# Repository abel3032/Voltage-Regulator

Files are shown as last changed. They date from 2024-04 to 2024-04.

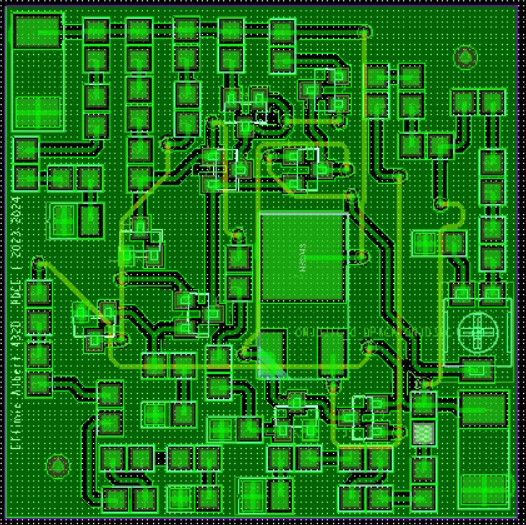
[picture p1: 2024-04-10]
Layout/layout.jpg

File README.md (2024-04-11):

Stabilizator de tensiune cu element de reglaj serie

Cu ajutorul programelor OrCAD, PSpice si PCBEditor am proiectat un stabilizator de tensiune cu element de reglaj serie respectand urmatoarele conditii:  
      -Tensiunea de la iesire reglabila in intervalul 6V - 12V   
      -Sarcina la iesire de 480 ohmi  
      -Deriva termica mai mica de 2mV/grad Celsius  
      -Protectia la suprasarcina prin limitarea temperaturii tranzistorului regulator serie la 120 grade Celsius si a curentului maxim la 0.5A  
      -Tensiunea de intrare in intervalul 21,6V - 24V  
      -Amplificarea in tensiune minima (in bucla deschisa) a amplificatorului de eroare minim 100    
      -Domeniul temperaturilor de functionare 0 - 60 grade Celsius    
      -Semnalizarea prezentei tensiunilor de intrare/iesire cu o dioda de tip LED

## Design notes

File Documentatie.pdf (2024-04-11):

# Universitatea “Politehnica” din Bucuresti

# FACULTATEA DE ELECTRONICA, TELECOMUNICATII SI TEHNOLOGIA INFORMATIEI

# STABILIZATOR DE TENSIUNE CU ERS

# Proiect 1

# Student: Eftimie Albert Gabriele

# Grupa: 432D

2023-2024

# 1. Date de proiectare

- N=12

# - Element de reglaj serie - Sarcina la iesire 480 ohmi - Deriva termica <2mV/grad Celsius

- Protecție la suprasarcină prin limitarea temperaturii tranzistorului regulator serie la 1200C, si a curentului maxim la 0,5A - Tensiunea de intrare in interval 21,6V-24V - Amplificarea în tensiune minimă (în buclă deschisă) a amplificatorului de eroare: minim 100 - Domeniul temperaturilor de funcționare: 0-60 Celsius (verificabil prin testare în temperatura) - Semnalizarea prezenței tensiunilor de intrare/ieșire cu diodă de tip LED

# 2. Schema bloc a circuitului

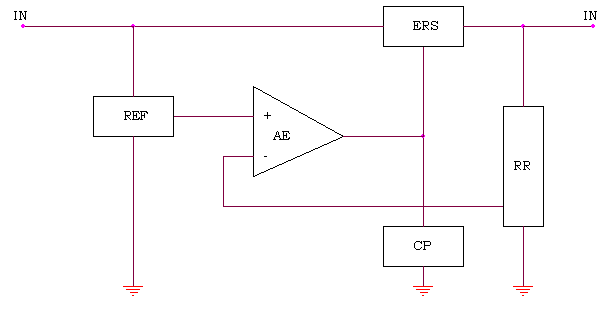
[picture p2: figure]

# 3. Schema electrica a circuitului

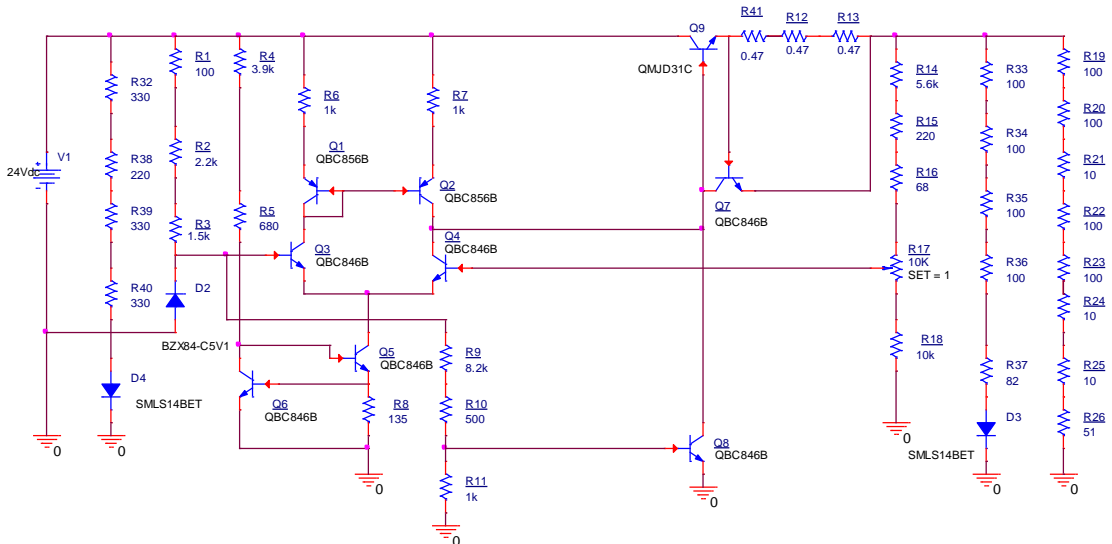
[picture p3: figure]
Q7 QBC846B; Q8 QBC846B; 24Vdc; SMLS14BET; R17 10K SET = 1; QMJD31C; BZX84-C5V1; Q1 QBC856B; Q2 QBC856B; Q3 QBC846B; Q4 QBC846B; Q5 QBC846B; Q6 QBC846B

# Blocurile componente ale stabilizatorului de tesniune sunt:

# -referinta de tensiune data de dioda Zener D2, polarizata de rezistoarele R1, R2 si R3; acestea s-au ales astfel incat prin dioda sa curga un curent de aprox 5 mA prin zener)

# -amplificatorul de eroare, alcatuit din Q3, Q4, amplificator alimentat la 2 surse de curent formate din R6, R7, Q1, Q2, respectiv R4, R5, R8, Q5, Q6; sursele de curent au fost dimensionate pentru a asigura prin ambele tranzistoare un curent aproximativ egal de 2.5mA

# -reteaua de reactie negativa formata din rezistoarele R14, R15, R16, R17, R18 (divizor de tensiune); Vout/Vin=10k/25.8k, unde Vout este tensiunea data de dioda Zener

# -circuitul de protectie la temperatura format din Q8, R9, R10 si R11; acesta a fost

dimensionat astfel pentru ca tensiunea baza-emitor a lui Q8 sa fie de 460-500mV,

# aceasta crescand odata cu cresterea temperaturii, la 120 grade celsius urmand sa se

0

# deschida tranzistorul. Tensiuneea Vbe este astfel setata cu ajutorul divizorului de

tesniune format din R9, R10 si R11.

# -circuitul de protectie la suprasarcina format din Q7, R12 si R13 a fost dimensionat astfel pentru a asigura o tensiune baza emitor de aprox 0.7V la un curent de 0.5A

# -elemntul de reglaj serie format din tranzistoarele Q9, s-a ales un tranzistor de putere in locul a ami multor tranzistori legati in paralel deoarece la capacitate maxima, asupra acestuia urma sa fie disipata o putere de peste 1.2W

# -cele 2 diode de semnalizare a tensiunii de la intrare si la iesire D2, D3 cu rezistoarele ce le polarizeaza R1, R2, R3 respectiv R33-R37

# 4. Simularile stabilizatorului

# -punctul static de functionare simulat(pentru potentiometrul setat pe 1 si tensiunea maxima de intrare)

# In figura de mai jos putem observa toti curentii din circuit

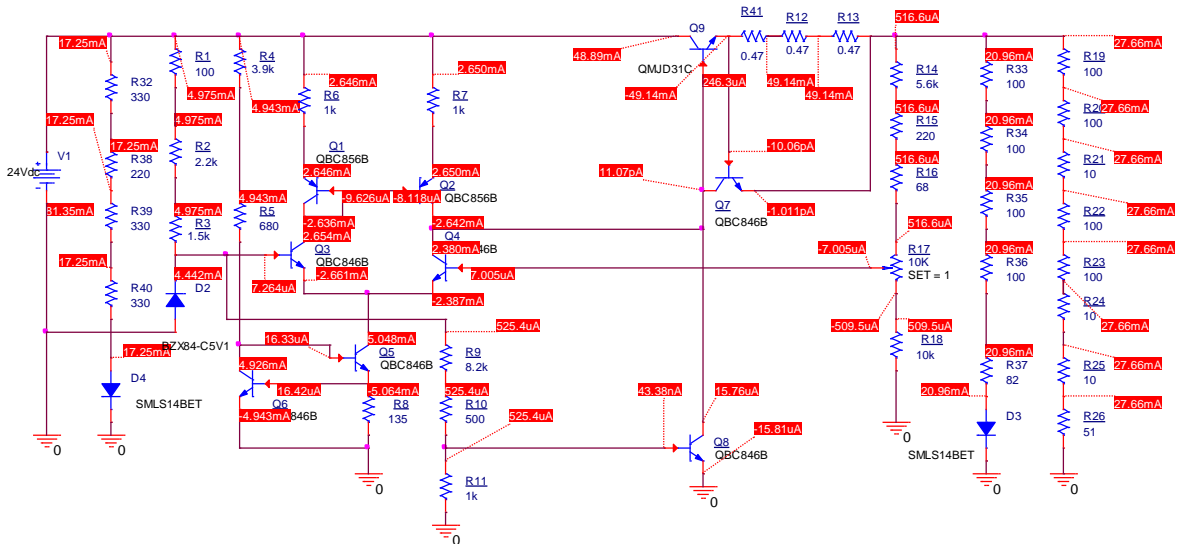
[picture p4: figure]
Q7 QBC846B; Q8 QBC846B; 24Vdc; SMLS14BET; R17 10K SET = 1; QMJD31C; BZX84-C5V1; Q1 QBC856B; Q2 -8.118uA QBC856B; Q3 QBC846B; QBC846B; Q5 QBC846B; Q6 QBC846B

0

# Se observa ca toate tranzistoarele bipolare sunt in regim activ de functionare(exceptie fac tranzistoarele din componenta circuitelor de protectie)

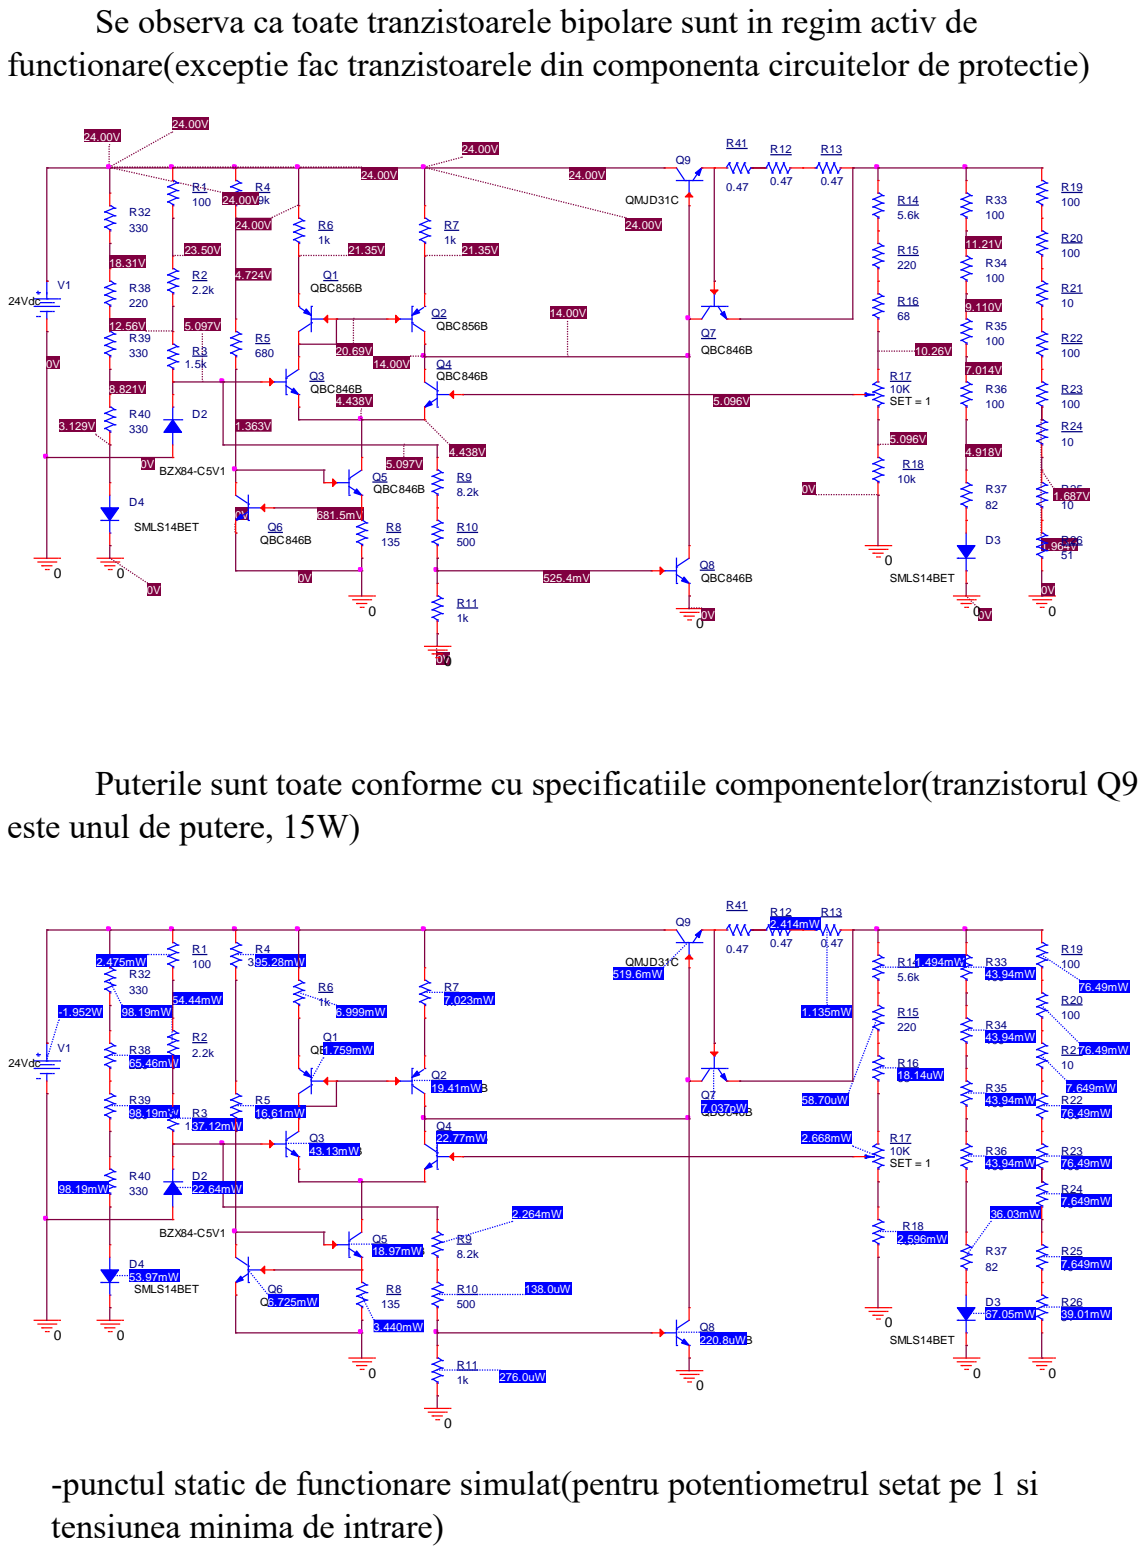
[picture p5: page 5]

Puterile sunt toate conforme cu specificatiile componentelor(tranzistorul Q9
este unul de putere, 15W)

-punctul static de functionare simulat(pentru potentiometrul setat pe 1 si
tensiunea minima de intrare)

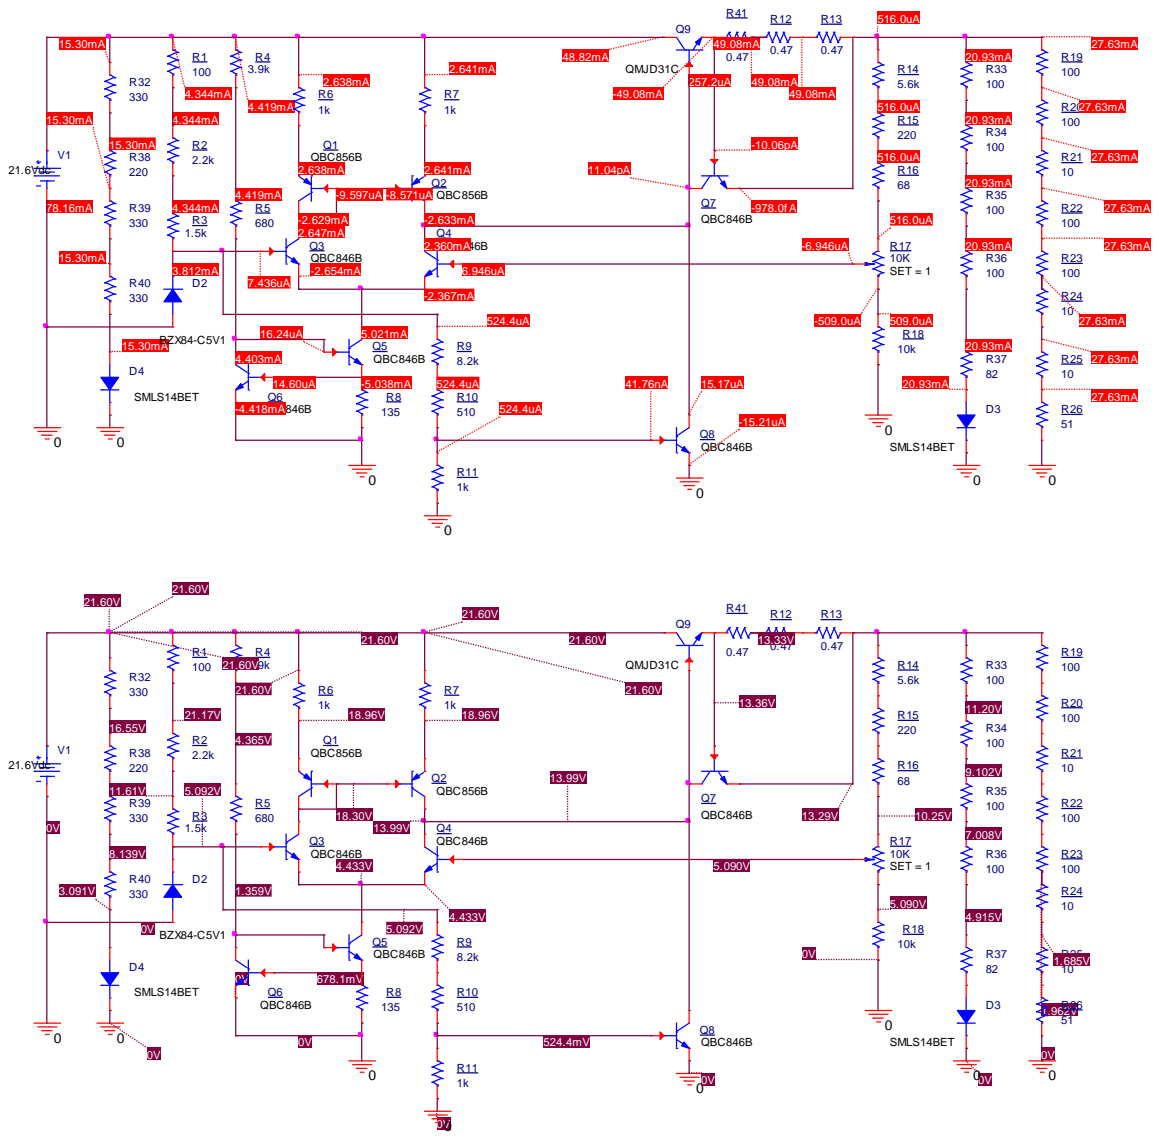
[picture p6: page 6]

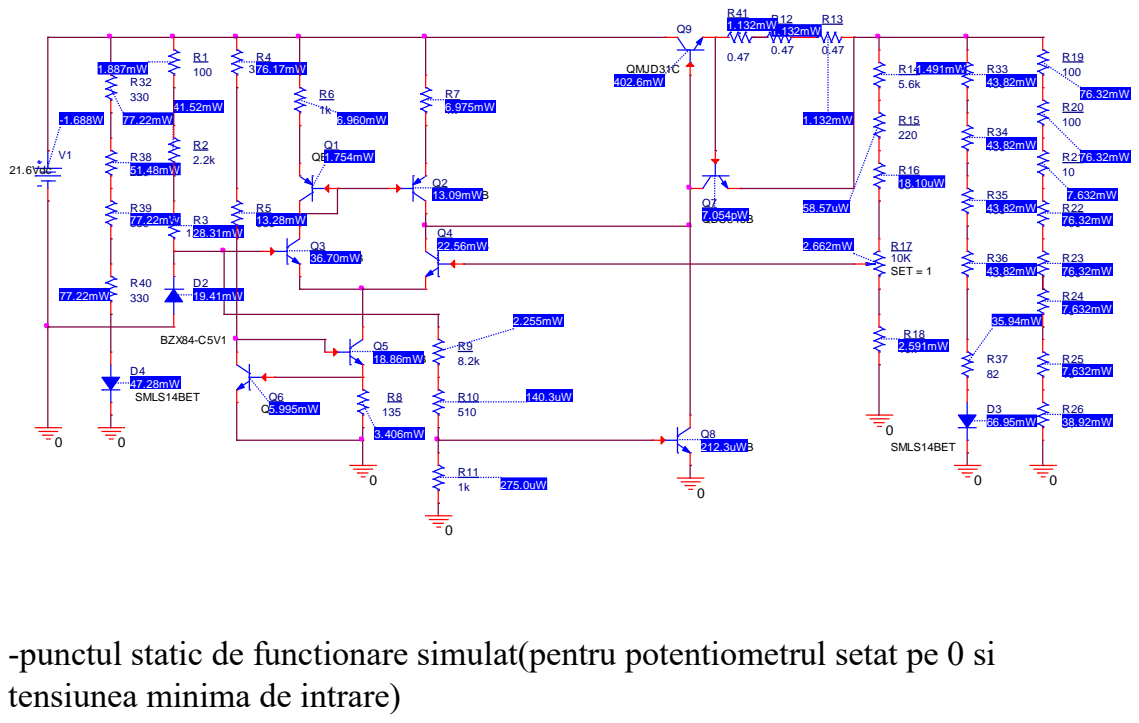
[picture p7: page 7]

-punctul static de functionare simulat(pentru potentiometrul setat pe 0 si
tensiunea minima de intrare)

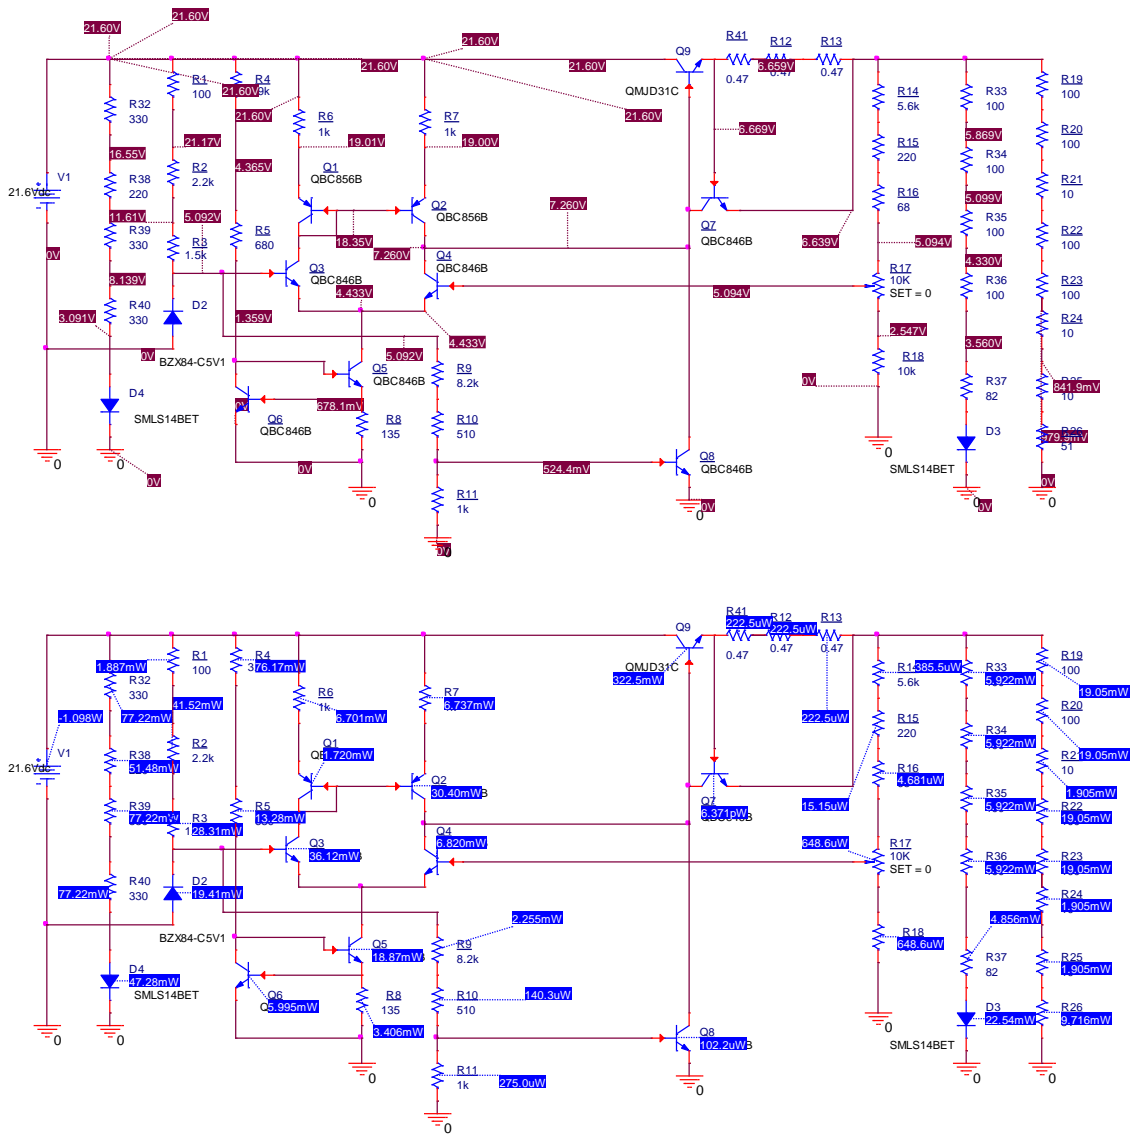
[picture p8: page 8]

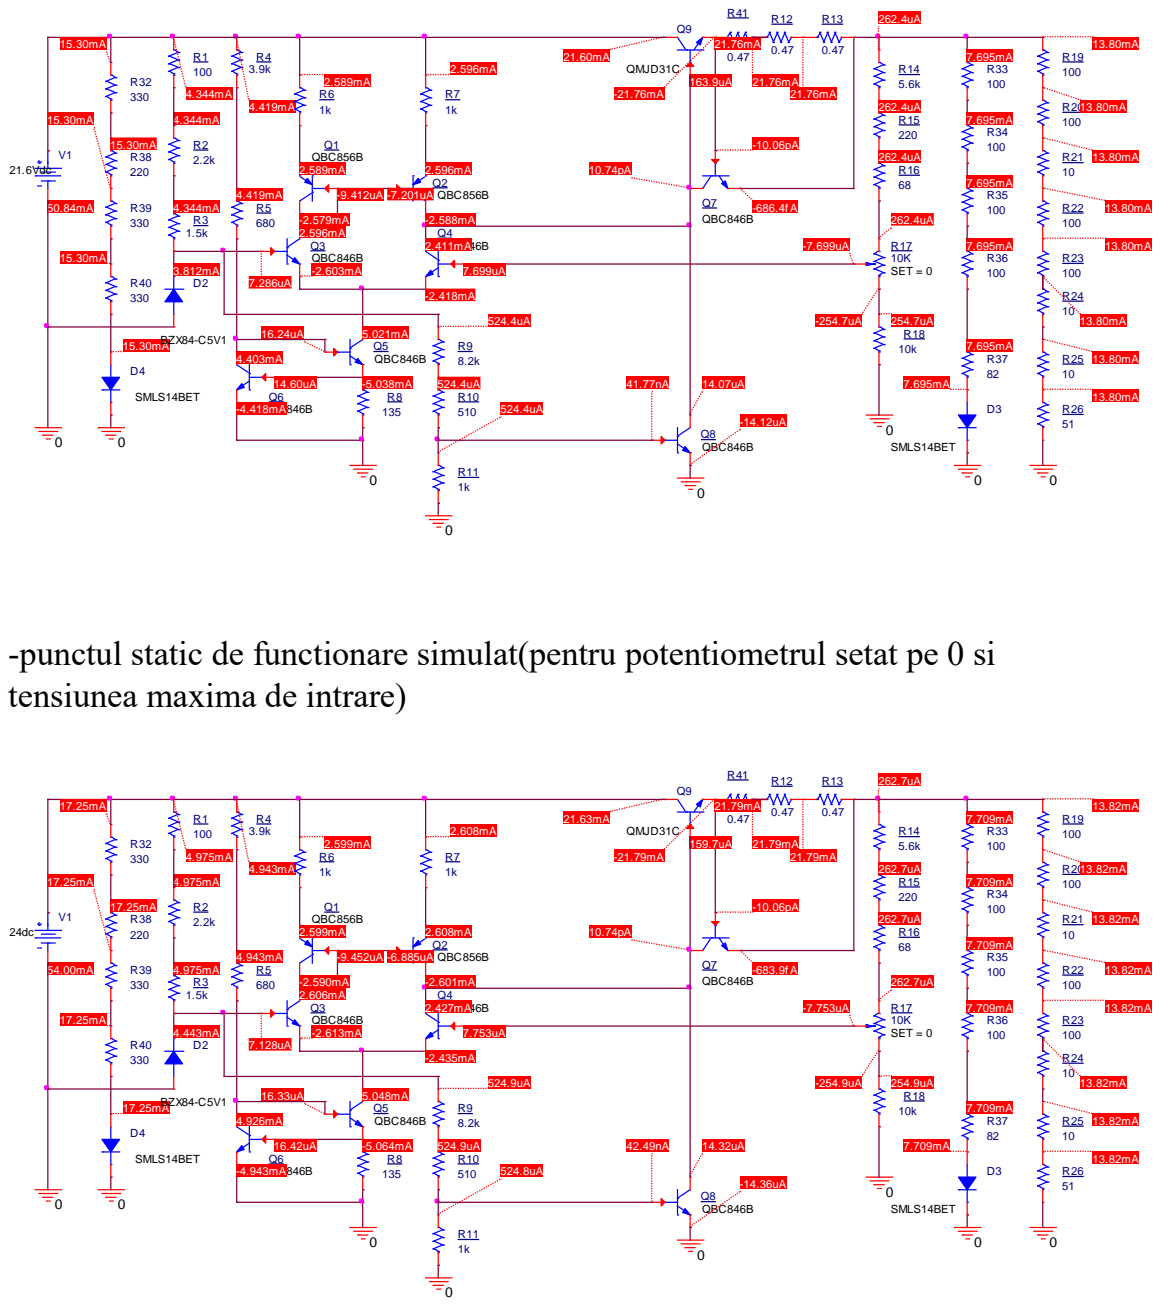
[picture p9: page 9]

-punctul static de functionare simulat(pentru potentiometrul setat pe 0 si
tensiunea maxima de intrare)

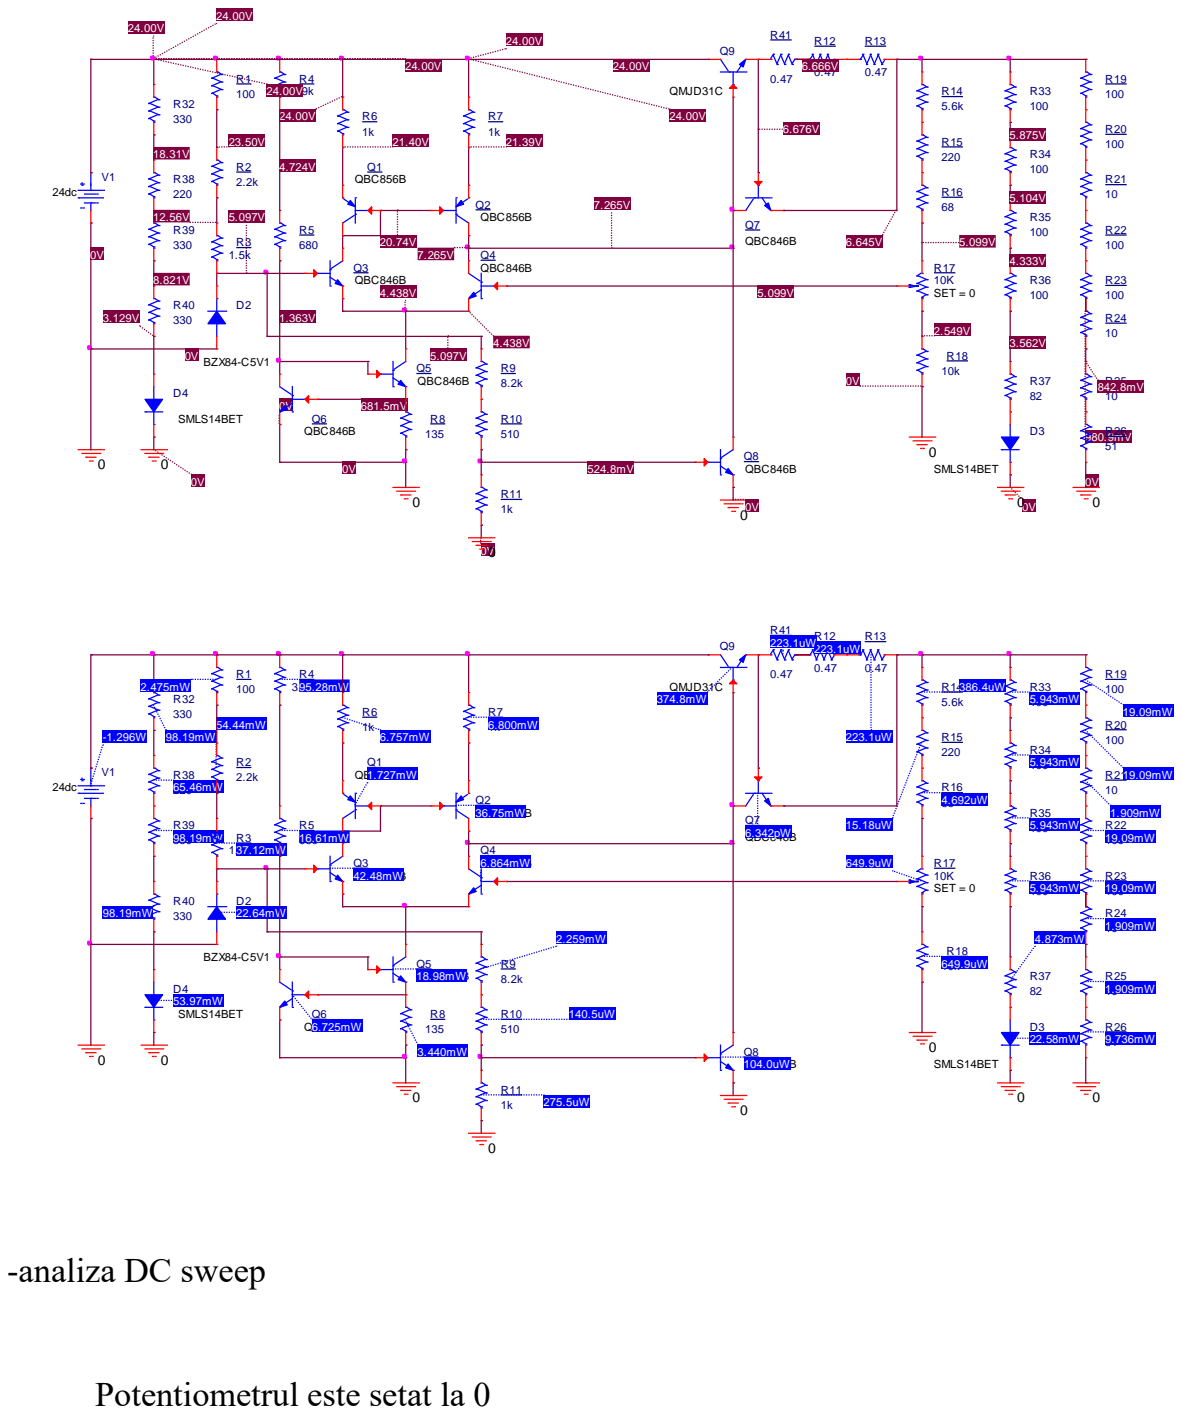
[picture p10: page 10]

Potentiometrul este setat la 0

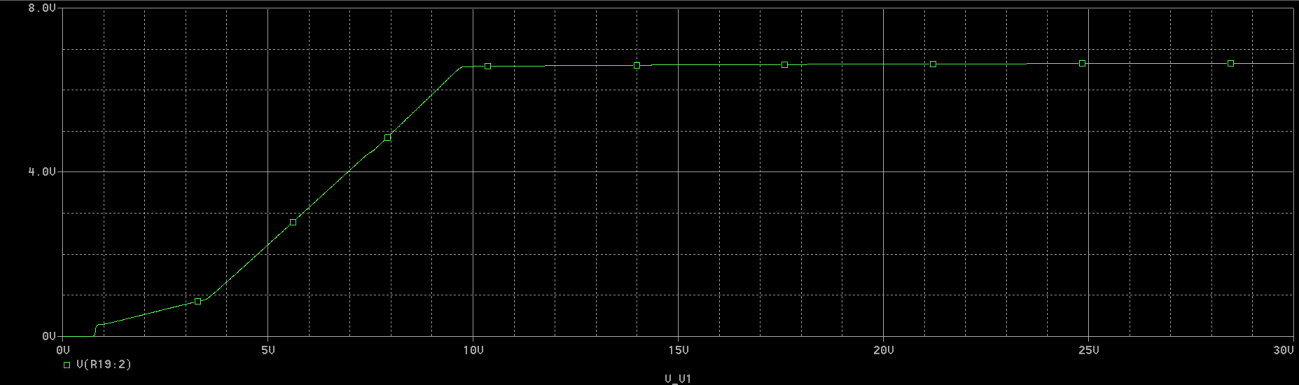
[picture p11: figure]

# Potentiometrul este setat la 1

# Am ales tensiuni de iesire cu 10% mai mari decat cele din cerinta din cauza

tolerantelor rezistoarelor.

Se observa ca intre tensiunile de intrare date in cerinta (21,6V – 24 V),

# tensiunile de iesire sunt constante in ambele cazuri, tensiunea de iesire avand o

variatie mai mica de 0.6mv/V .

# -domeniul temperaturilor de functionare

# -analiza s-a facut pentru temperaturile 0, 20, 40 respectiv 60 grade Celsius

# -pentru tensiunea minima la iesire

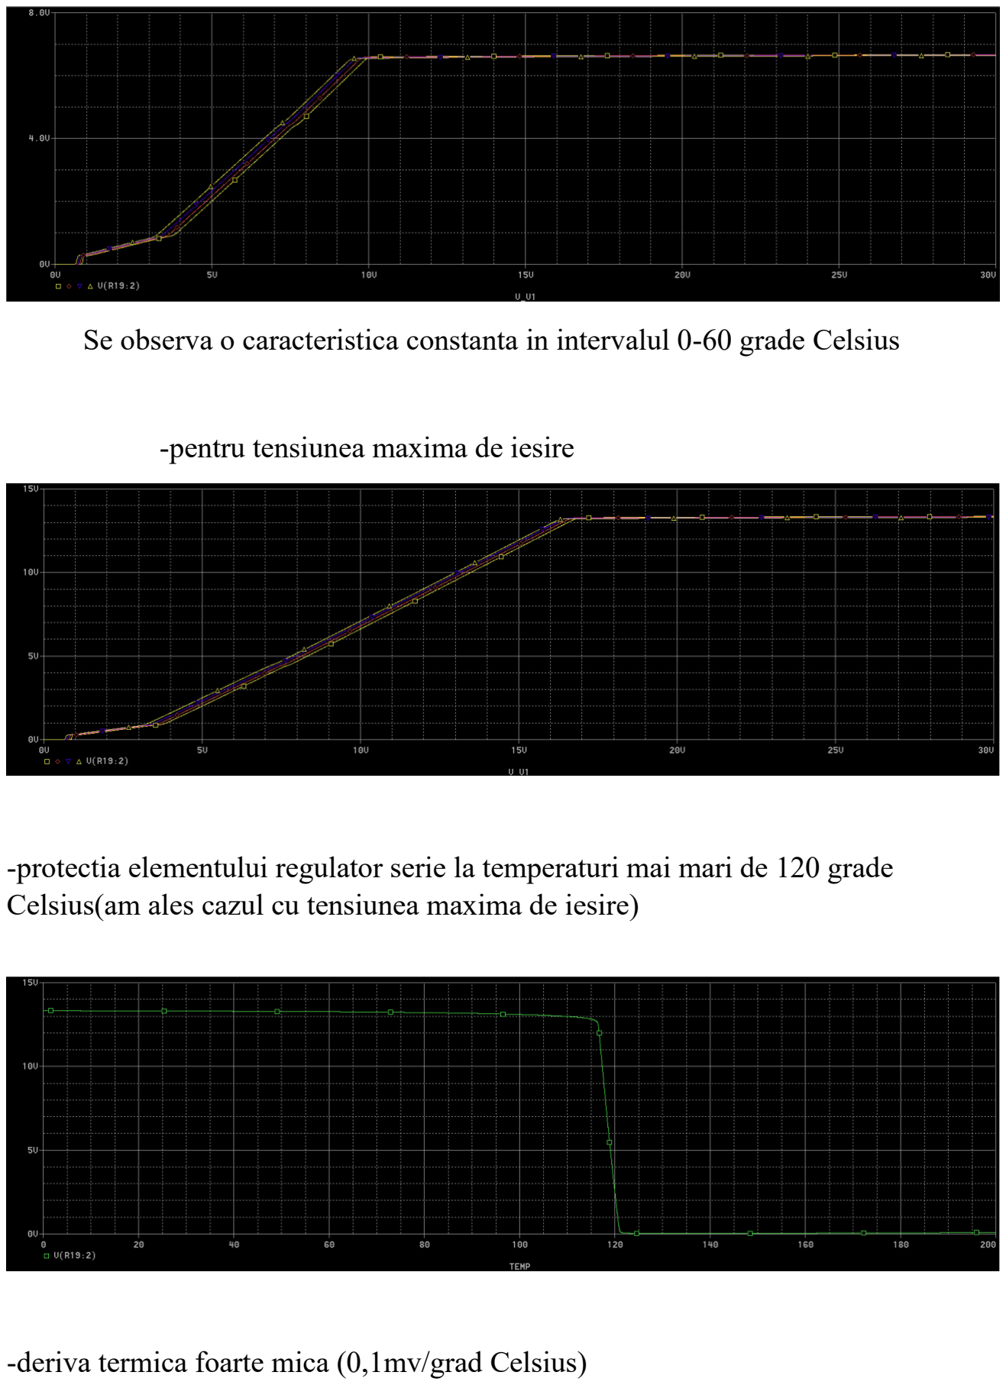
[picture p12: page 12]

# Se observa o caracteristica constanta in intervalul 0-60 grade Celsius

# -pentru tensiunea maxima de iesire

# -protectia elementului regulator serie la temperaturi mai mari de 120 grade Celsius(am ales cazul cu tensiunea maxima de iesire)

# -deriva termica foarte mica (0,1mv/grad Celsius)

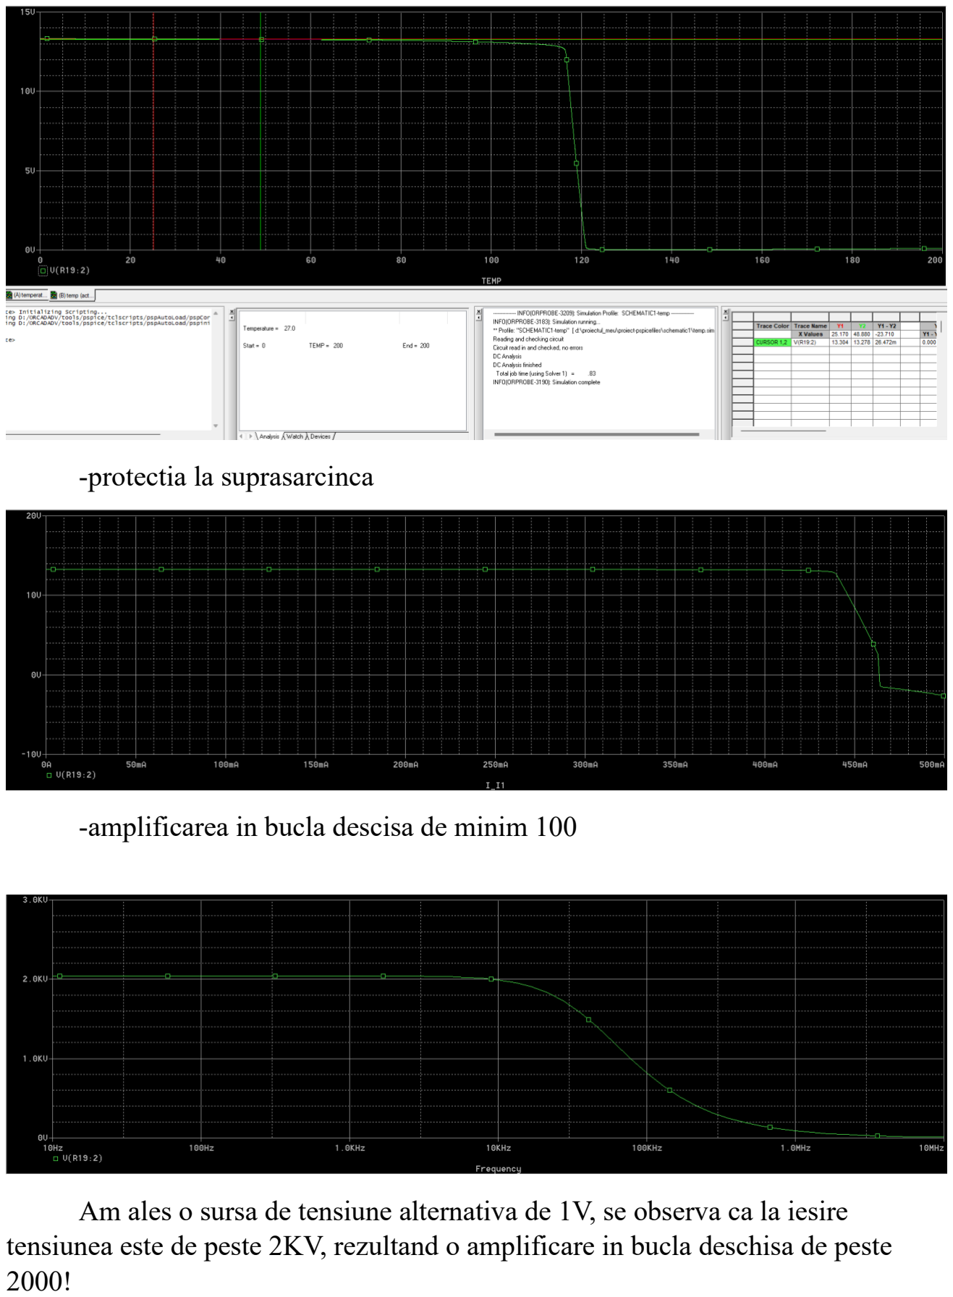
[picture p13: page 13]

# -protectia la suprasarcinca

# -amplificarea in bucla descisa de minim 100

# Am ales o sursa de tensiune alternativa de 1V, se observa ca la iesire tensiunea este de peste 2KV, rezultand o amplificare in bucla deschisa de peste

2000!

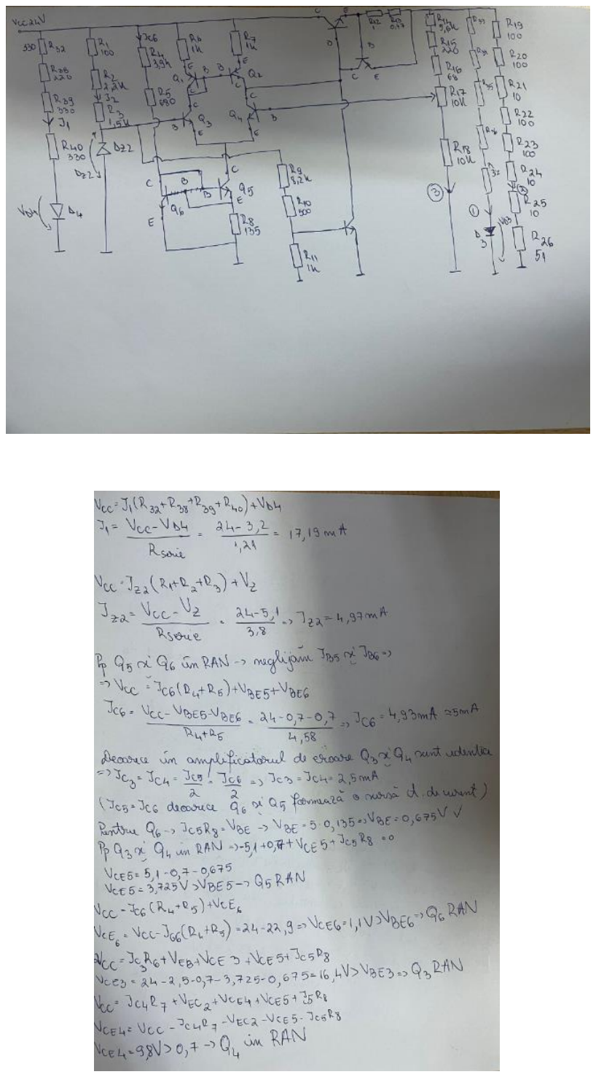
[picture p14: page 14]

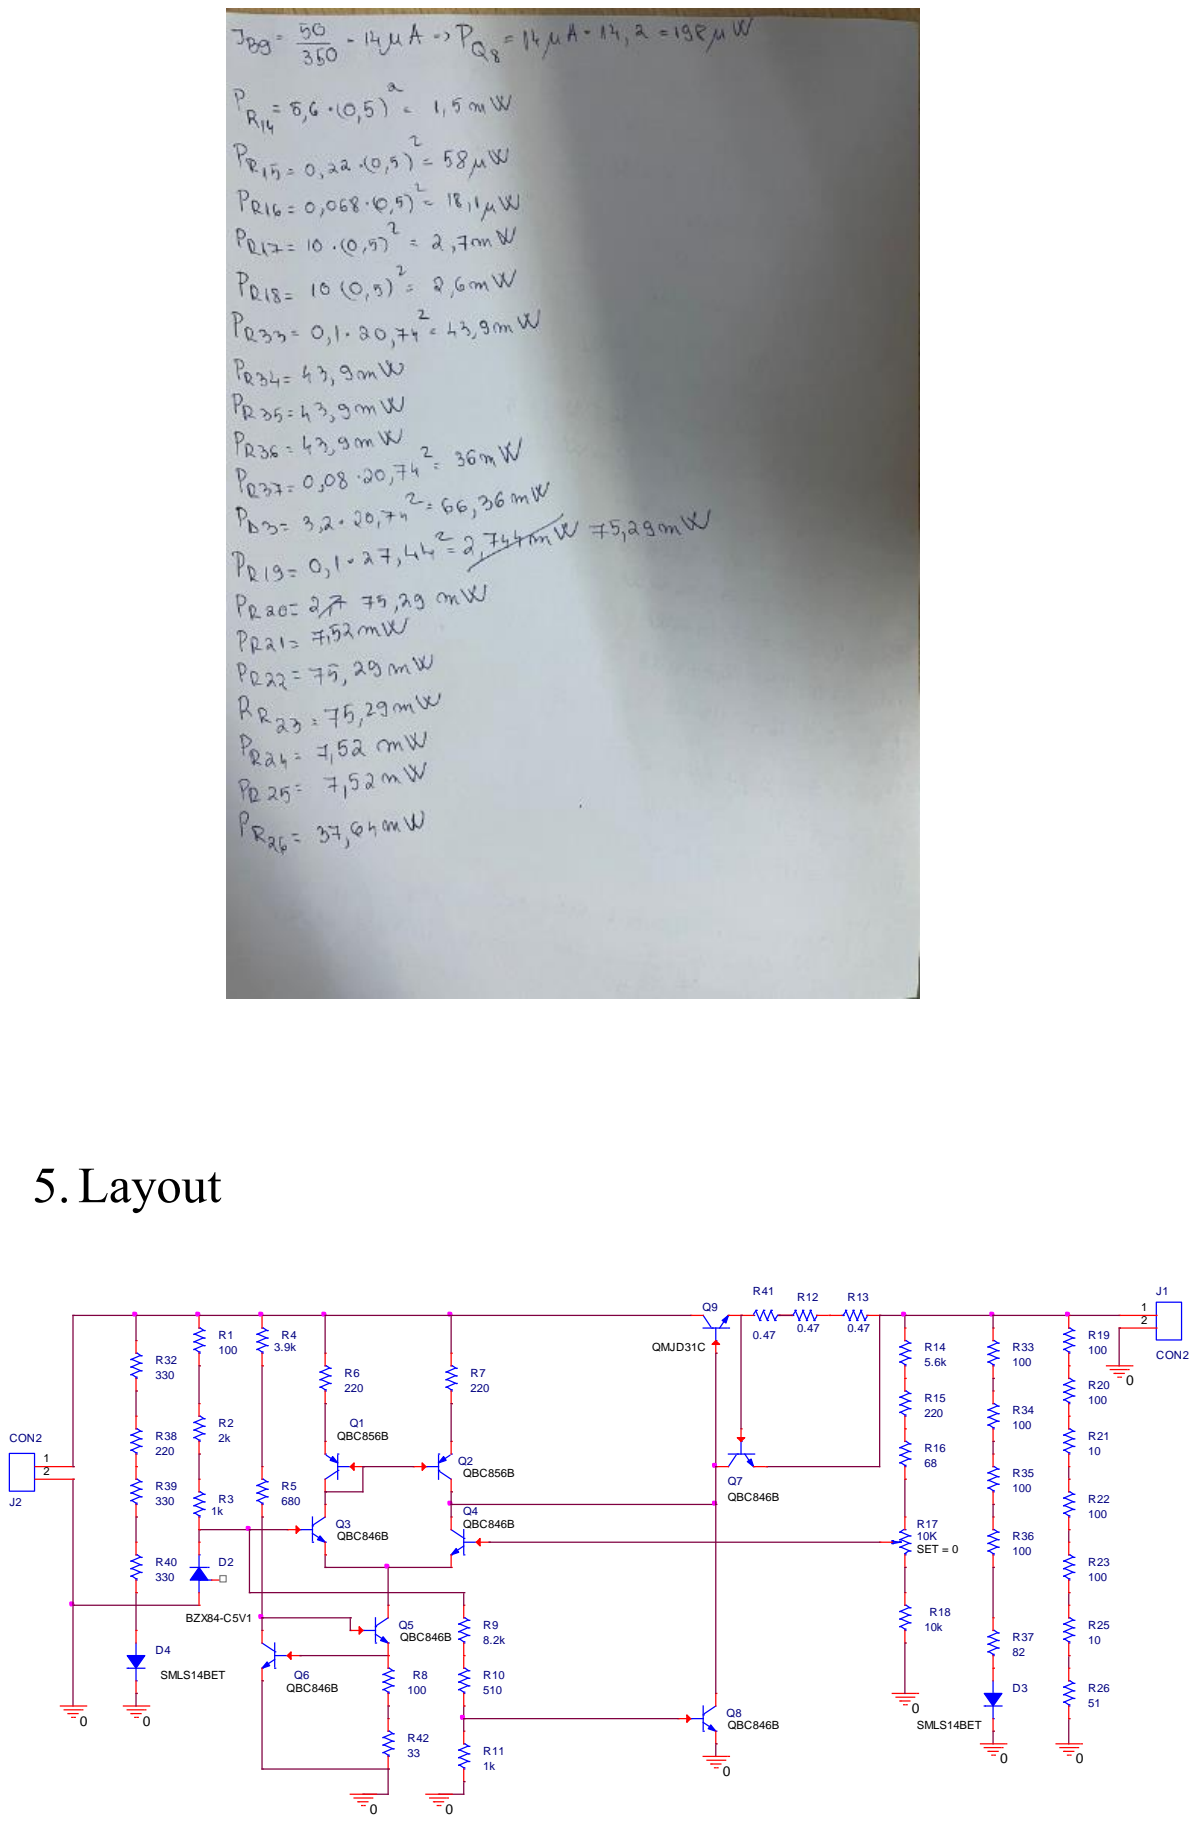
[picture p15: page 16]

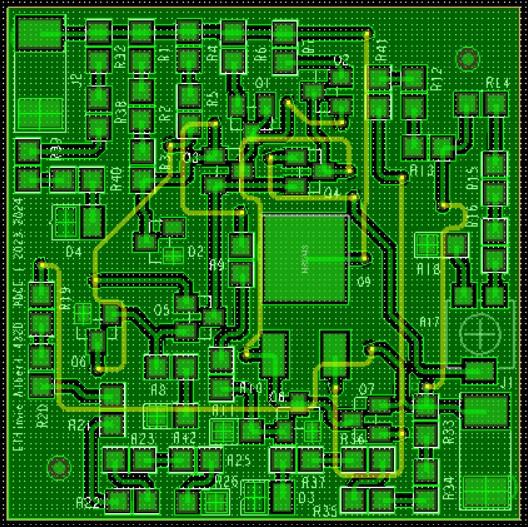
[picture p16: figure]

# Capsule utilizate

- Rezistoare: | SMR0805
- Tranzistoare: | TO236AA
- Dioda Zener: | TO236AA
- Diodele led: | SMD0805

# - Potentiometru: TS53YL - Conectori: SMR2512

# In alcatuirea PCB-ului am tinut cont de mai multe aspecte tehnologice, cum ar fi plasarea componentelor asupra carora se disipa cea mai mare putere in centrul

# placii. S-au evitat unghiurile de 90 de grade pe acelasi strat, iar trecerea de pe un strat pe altul prin intermediul vias-urilor s-a realizat la un unghi de 90 de

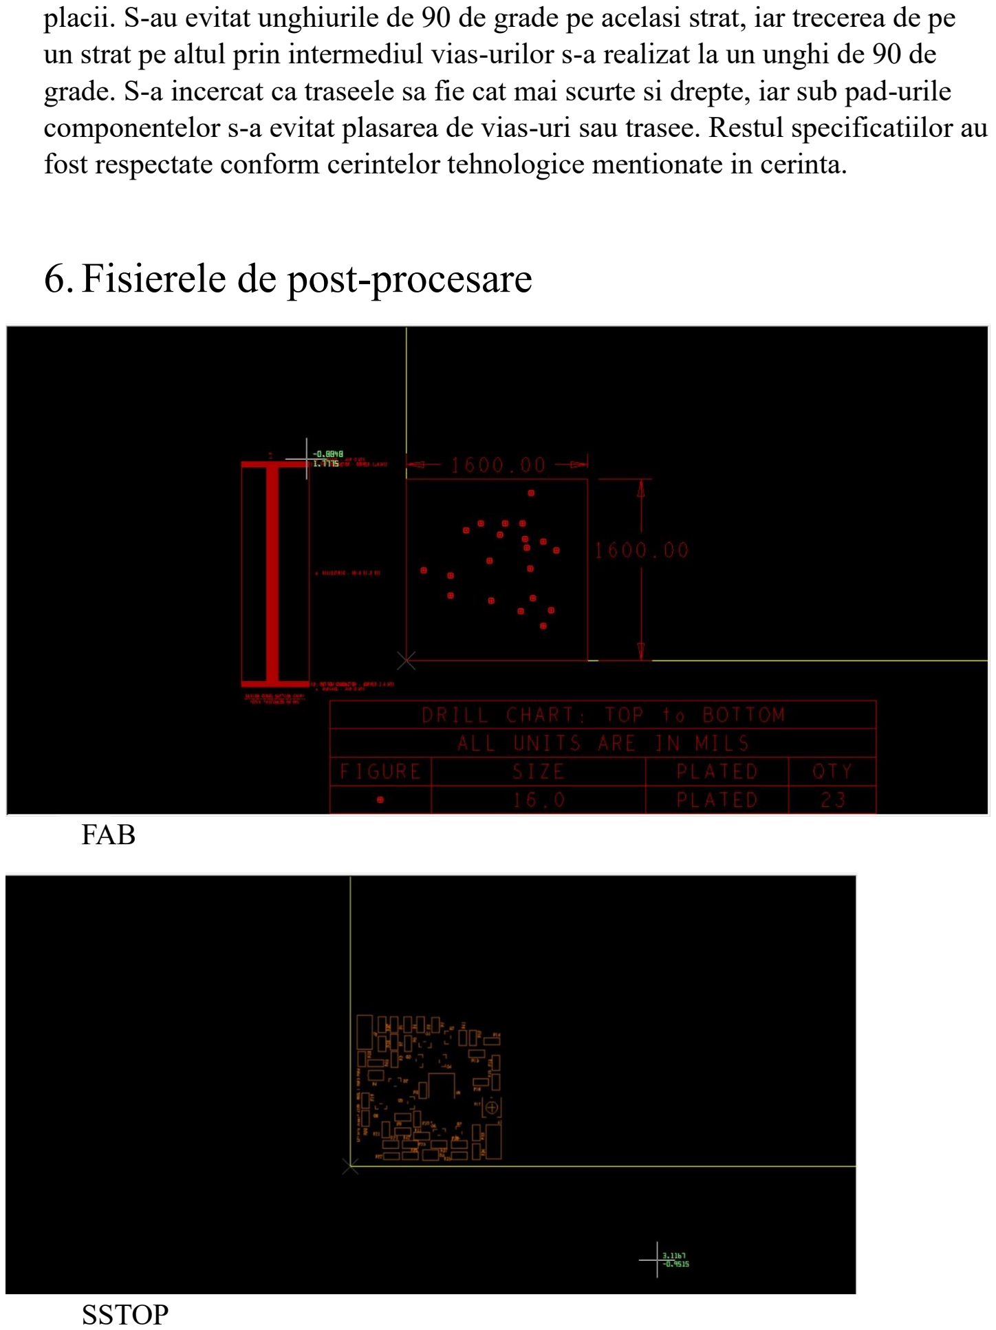
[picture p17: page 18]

# grade. S-a incercat ca traseele sa fie cat mai scurte si drepte, iar sub pad-urile componentelor s-a evitat plasarea de vias-uri sau trasee. Restul specificatiilor au

fost respectate conform cerintelor tehnologice mentionate in cerinta.

# 6. Fisierele de post-procesare

# 7.Bibliografie:

# - Note de curs - Circuite electronice fundamentale, Dragoș Dobrescu

# - „Circuite Electronice Fundamentale” Gheorghe Brezeanu, Florin Draghici

# - https://www.tme.eu/ro/

# - https://ro.wikipedia.org/wiki/Stabilizator_de_tensiune

# FAB

# SSTOP

# SPTOP

# SMBOT

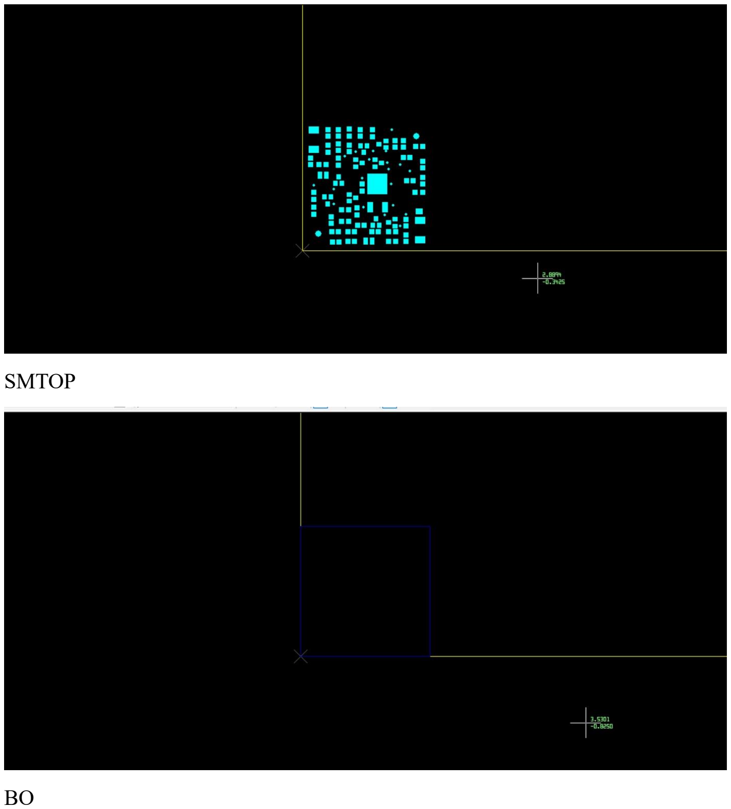
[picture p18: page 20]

# SMTOP

BO

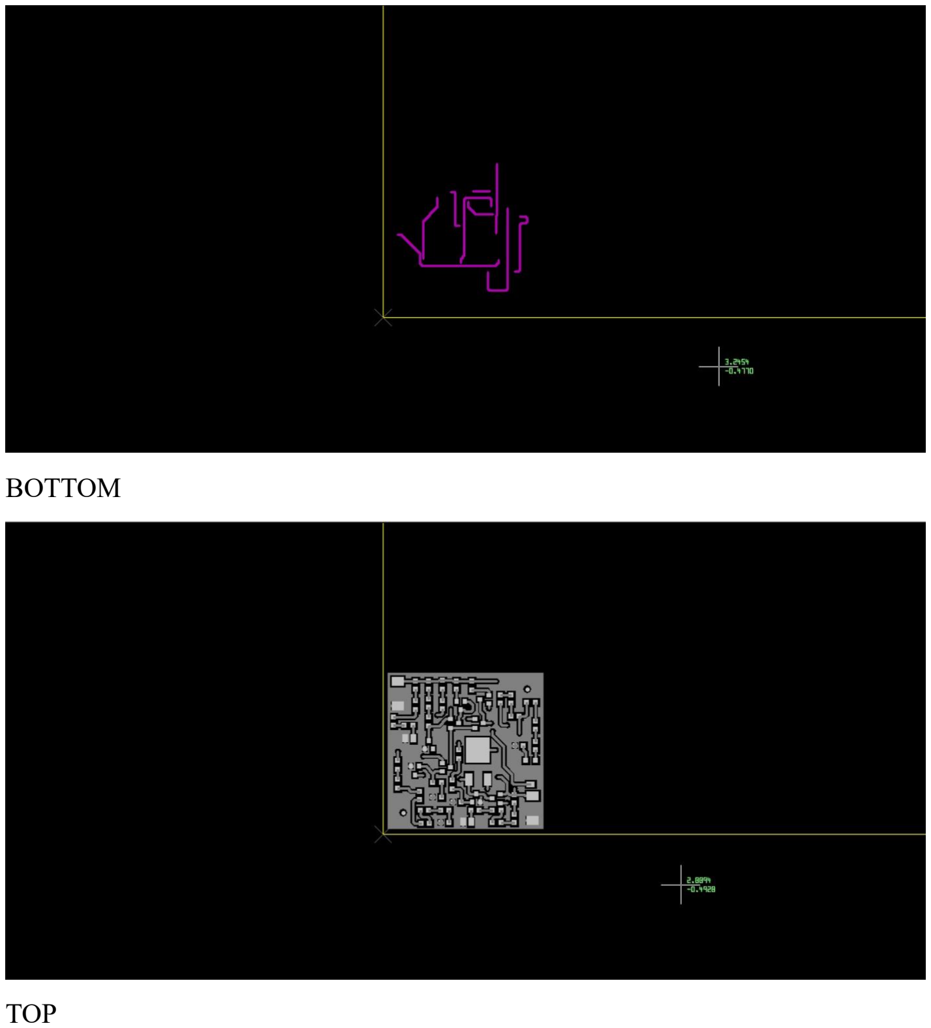
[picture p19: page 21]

# BOTTOM

# TOP

# DRILL

# TOATE

# 7.Asamblarea PCB-ului

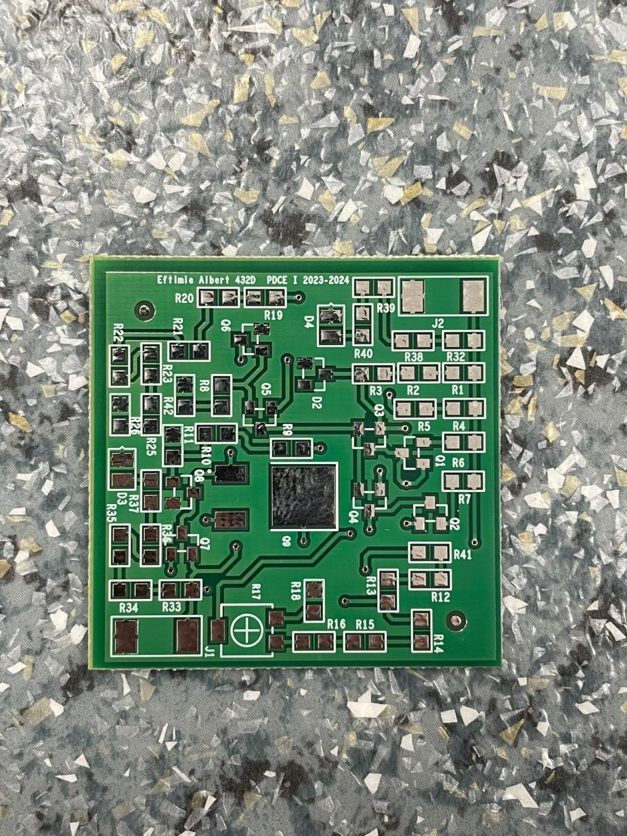
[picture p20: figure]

# PCB in starea initiala

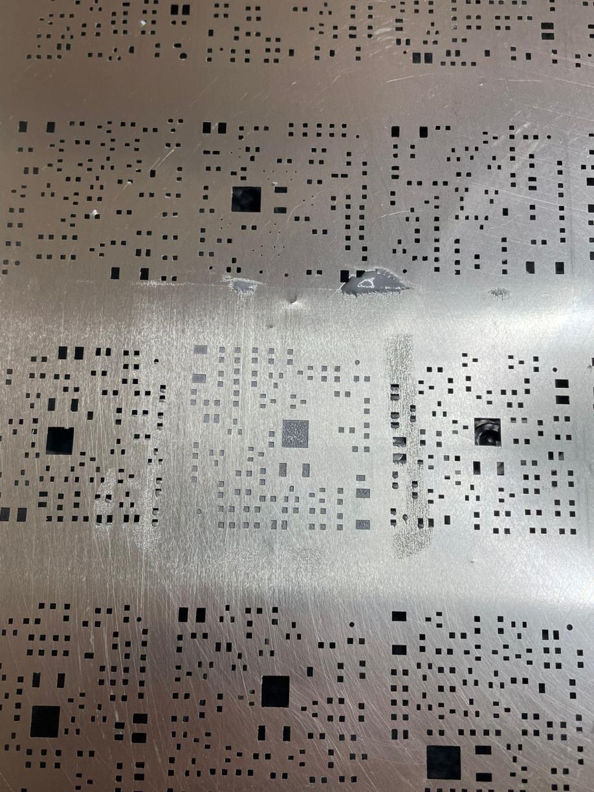
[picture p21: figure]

# Aplicarea aliajului

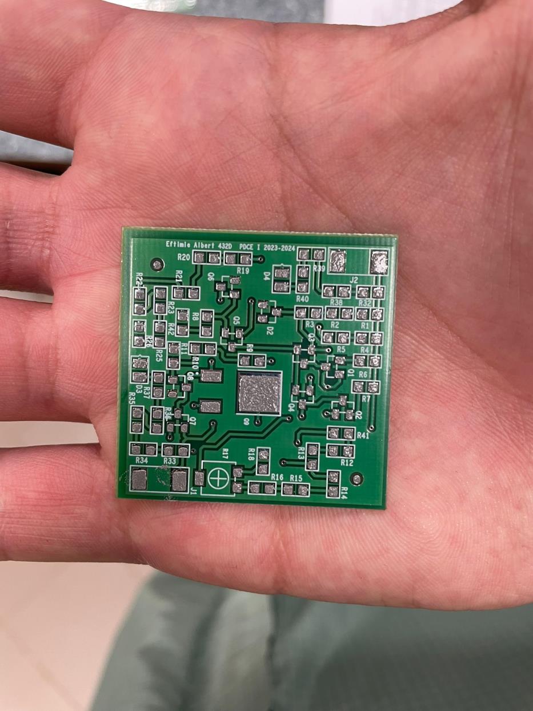
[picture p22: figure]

# PCB-ul dupa aplicarea aliajului

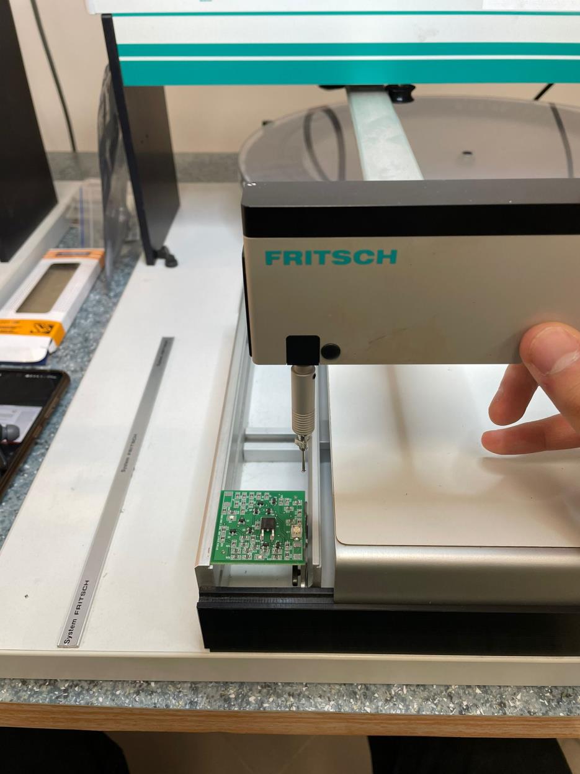
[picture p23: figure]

# Plasarea componentelor cu ajutorul aparatului

# pick & place

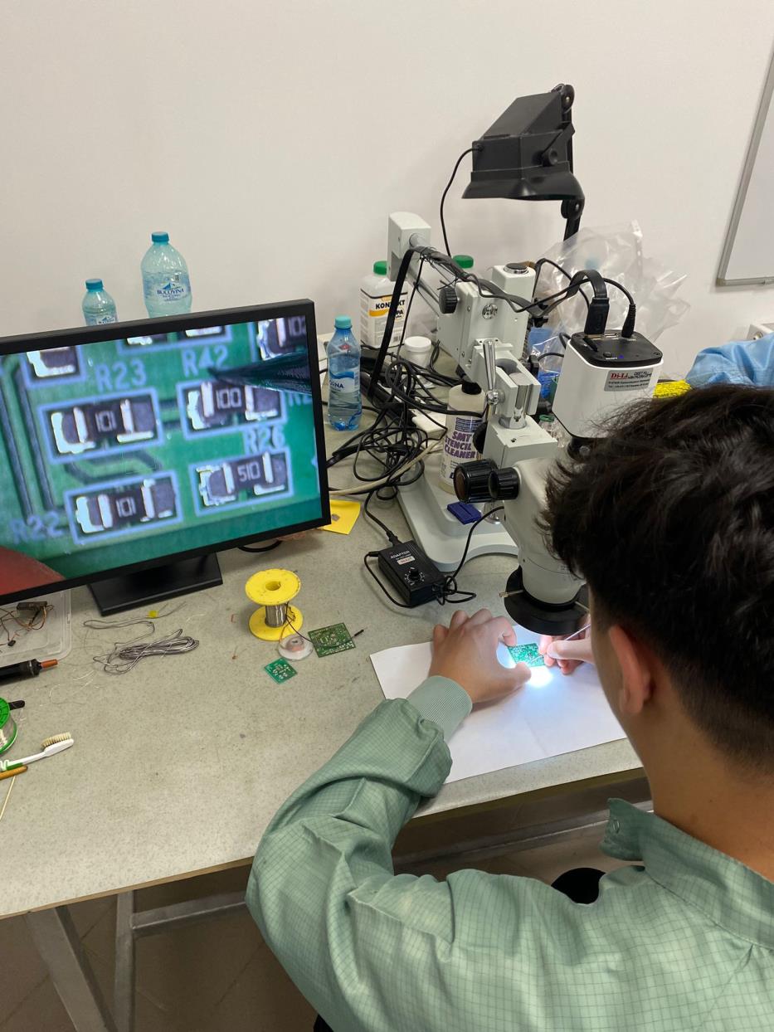
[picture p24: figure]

# Indreptarea componentelor

# Plasarea PCB-ului in cuptor

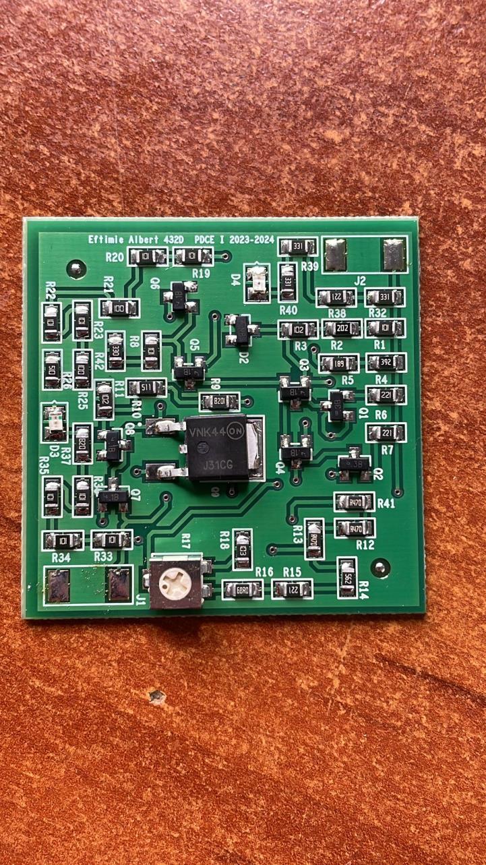
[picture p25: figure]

# Rezultatul final

# 8. Probleme intampinate

De-a lungul proiectului am intampinat multe probleme de proiectare.

Probabil cea mai des intalnita a fost puterea disipata pe rezistoare. Aceasta nu trebuia sa depaseasca 125 mW, dar pentru a fi sigur, am optat pentru o putere disipata maxima de aproximativ 100 mW. Pentru a rezolva aceasta problema am apelat la "spargerea" rezistoarelor in mai multe rezistoare de rezistenta egala. Astfel, puterea disipata pe acestea s-a incadrat in normele

impuse.

O alta problema intampinata a fost plasarea ideala a componentelor: cele active ce disipa cea mai multa putere sa fie plasate in mijlocul PCB-ului, iar cele pasive pe marginea acestuia. Astfel au aparut alte probleme cum ar fi trasarea rutelor optime, fara unghiuri de 90 de grade, respectarea dimensiunii vias-urilor si a marker-ilor fiduciali. Toate aceste aspecte au dus la multiple reincercari de proiectare a PCB-ului, pana cand in final s-a ajuns

la o forma aproximativ optima.

Cea mai mare problema dupa parerea mea a fost fixarea componentelor pe PCB in urma aplicarii aliajului. Cu ajutorul microscopului si al unei scobitori metalice am mutat cu mare atentie componentele astfel incat acestea sa fie perfect asezate pe pad-uri, insa fiind foarte mici a fost foarte usor sa le

miscam gresit.

# 9. Bibliografie

- „Circuite Electronice Fundamentale” -probleme- Gheorghe Brezeanu,

# Florin Draghici, Florin Mitu, Gheorghe Dilimot - „Circuite Electronice Fundamentale” Gheorghe Brezeanu, Florin Draghici - https://www.tme.eu/ro/ - https://ro.wikipedia.org/wiki/Stabilizator_de_tensiune - Note de curs - Circuite electronice fundamentale, Dragoș Dobrescu

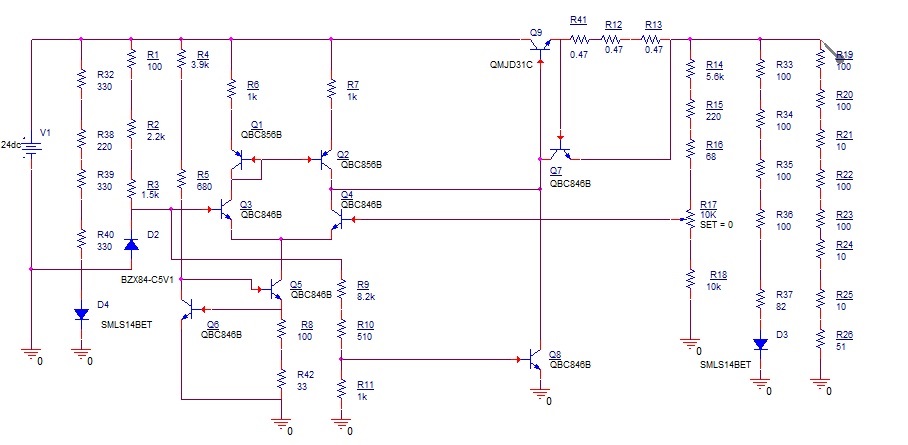
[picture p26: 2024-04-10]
Schematics/Etapa1/CIRCUIT.jpg

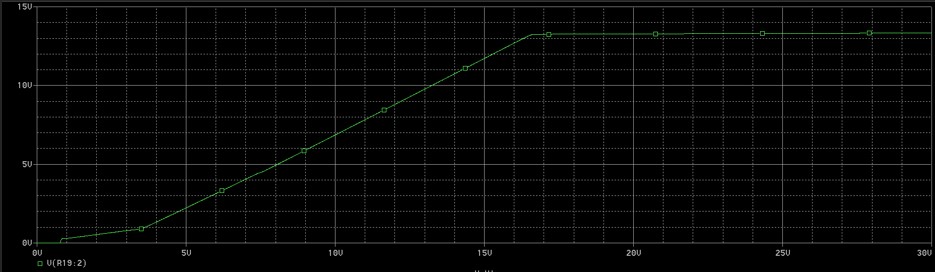
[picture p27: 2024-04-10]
Simulations/Vout_tensiune_maxima.jpg

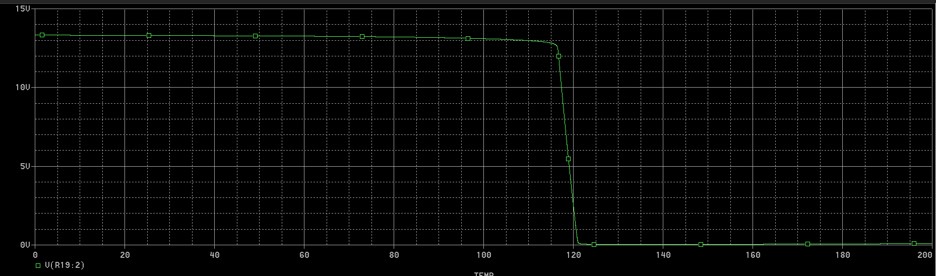
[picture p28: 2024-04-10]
Simulations/Protectie_temperatura.jpg

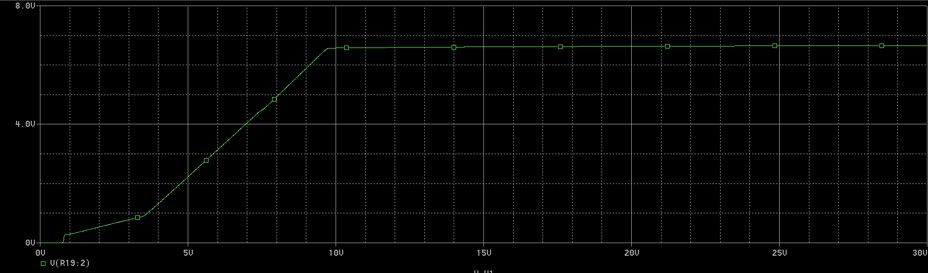
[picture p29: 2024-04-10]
Simulations/Vout_tensiune_minima.jpg

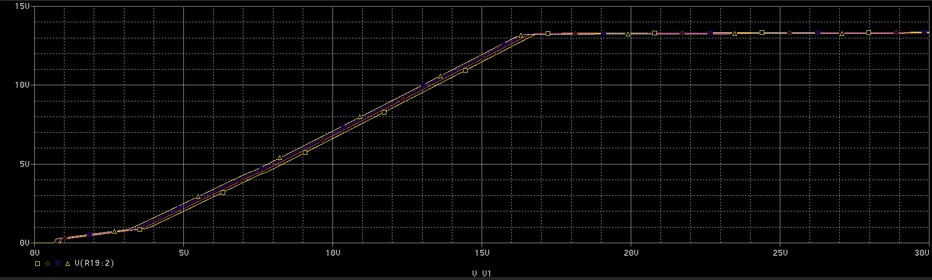
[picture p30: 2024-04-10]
Simulations/Vout_maxim_interval_0_60.jpg

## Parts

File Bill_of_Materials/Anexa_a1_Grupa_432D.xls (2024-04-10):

Anexa a1 - Grupa 432D - Tema 3 - Stabilizator de tensiune cu ERS
Nr. Crt. | Nume | Catalog | Cod distrib | Nume prod | Prod | Clasă | Qty fix | Qty final | Qty min | Descriere | Distribuitor | Pret (fara TVA) referinta/buc. TME România | Pret total pe reper (fara TVA) - propus
1 | 0 ohm | (LINK) (http://www.tme.eu/ro/details/smd1206-0r/rezistente-smd-1206/royal-ohm/1206s4j0000t5e/) | 1206S4J0000T5E | 1206S4J0000T5E | SR PASSIVES | rezistor | 0 |  |  | Rezistor: thick film; SMD; 1206; 0Ω; 0,25W; ±5%; -55÷125°C | TME România | 0.03841 | 0
2 | 0.47 | (LINK) (http://www.tme.eu/ro/details/smd0805-0r47/rezistente-smd-0805/royal-ohm/0805s8j047kt5e/) | SMD0805-0R47 | 0805S8J047KT5E | ROYAL OHM | rezistor | 20 |  | 3 | Rezistor SMD, chip, 0805, 0.47Ω, ±5%, 0.125W | TME România | 0.01454 | 0.2908
3 | 1 | (LINK) (https://www.tme.eu/ro/details/smd0805-1r/rezistente-smd-0805/royal-ohm/0805s8j010jt5e/) | SMD0805-1R-5% | 0805S8J010JT5E | ROYAL OHM | rezistor | 20 |  |  | Rezistor SMD, chip, 0805, 1Ω, ±5%, 0.125W | TME România | 0.01723 | 0.3446
4 | 4.7 | (LINK) (https://www.tme.eu/ro/details/smd0805-4r7/rezistente-smd-0805/royal-ohm/0805s8j047jt5e/) | SMD0805-4R7-5% | 0805S8J047JT5E | ROYAL OHM | rezistor | 10 |  |  | Rezistor SMD, chip, 0805, 4.7Ω, ±5%, 0.125W | TME România | 0.01723 | 0.1723
5 | 10 | (LINK) (https://www.tme.eu/ro/details/smd0805-10r/rezistente-smd-0805/royal-ohm/0805s8j0100t5e/) | SMD0805-10R-5% | 0805S8J0100T5E | ROYAL OHM | rezistor | 10 |  | 2 | Rezistor SMD, chip, 0805, 10Ω, ±5%, 0.125W | TME România | 0.01723 | 0.1723
6 | 22 | (LINK) (https://www.tme.eu/ro/details/smd0805-22r-1%25/rezistente-smd-0805/royal-ohm/0805s8f220jt5e/) | SMD0805-22R-1% | 0805S8F220JT5E | ROYAL OHM | rezistor | 20 |  |  | Rezistor SMD, chip, 0805, 22Ω, ±1%, 0.125W | TME România | 0.02127 | 0.4254
7 | 33 | (LINK) (https://www.tme.eu/ro/details/smd0805-33r/rezistente-smd-0805/royal-ohm/0805s8j0330t5e/) | SMD0805-33R-5% | 0805S8J0330T5E | ROYAL OHM | rezistor | 20 |  | 1 | Rezistor SMD, chip, 0805, 33Ω, ±5%, 0.125W | TME România | 0.01723 | 0.3446
8 | 51 | (LINK) (http://www.tme.eu/ro/details/rc0805jr-0751r/rezistente-smd-0805/yageo/rc0805jr-0751rl/) | SMD0805-51R-5% | 0805S8J0510T5E | ROYAL OHM | rezistor | 40 |  | 1 | Rezistor SMD, chip, 0805, 51Ω, ±5%, 0.125W | TME România | 0.0261 | 1.044
9 | 68 | (LINK) (http://www.tme.eu/ro/details/smd0805-68r-1%25/rezistente-smd-0805/royal-ohm/0805s8f680jt5e/) | SMD0805-68R-1% | 0805S8F680JT5E | ROYAL OHM | rezistor | 10 |  | 1 | Rezistor SMD, chip, 0805, 68Ω, ±1%, 0.125W | TME România | 0.04662 | 0.4662
10 | 82 | (LINK) (https://www.tme.eu/ro/details/wf08p-82r-5%25/rezistente-smd-0805/walsin/wf08p820jtl/) | SMD0805-82R-5% | WF08P820JTL | WALSIN | rezistor | 20 |  | 1 | Rezistor SMD, chip, 0805, 82Ω, ±5%, 0.125W | TME România | 0.0172 | 0.344
11 | 100 | (LINK) (https://www.tme.eu/ro/details/smd0805-100r/rezistente-smd-0805/royal-ohm/0805s8j0101t5e/) | SMD0805-100R-5% | 0805S8J0101T5E | ROYAL OHM | rezistor | 60 |  | 10 | Rezistor SMD, chip, 0805, 100Ω, ±5%, 0.125W | TME România | 0.01723 | 1.0338
12 | 150 | (LINK) (https://www.tme.eu/ro/details/smd0805-150r/rezistente-smd-0805/royal-ohm/0805s8j0151t5e/) | SMD0805-150R-5% | 0805S8F1500T5E | ROYAL OHM | rezistor | 30 |  |  | Rezistor SMD, chip, 0805, 150Ω, ±5%, 0.125W | TME România | 0.01723 | 0.5169
13 | 220 | (LINK) (http://www.tme.eu/ro/details/smd0805-220r-1%25/rezistente-smd-0805/royal-ohm/0805s8f2200t5e/) | SMD0805-220R-5% | 0805S8J0221T5E | ROYAL OHM | rezistor | 30 |  | 4 | Rezistor SMD, chip, 0805, 220Ω, ±5%, 0.125W | TME România | 0.02127 | 0.6381
14 | 330 | (LINK) (https://www.tme.eu/ro/details/smd0805-330r/rezistente-smd-0805/royal-ohm/0805s8j0331t5e/) | SMD0805-330R-5% | 0805S8J0331T5E | ROYAL OHM | rezistor | 30 |  | 3 | Rezistor SMD, chip, 0805, 330Ω, ±5%, 0.125W | TME România | 0.01723 | 0.5169
15 | 470 | (LINK) (https://www.tme.eu/ro/details/smd0805-470r/rezistente-smd-0805/royal-ohm/0805s8j0471t5e/) | SMD0805-470R-5% | 0805S8J0471T5E | ROYAL OHM | rezistor | 30 |  |  | Rezistor SMD, chip, 0805, 470Ω, ±5%, 0.125W | TME România | 0.01723 | 0.5169
16 | 510 | (LINK) (https://www.tme.eu/ro/details/smd0805-510r/rezistente-smd-0805/royal-ohm/0805s8j0511t5e/) | SMD0805-510R-5% | 0805S8J0511T5E | YAGEO | rezistor | 30 |  | 1 | Rezistor SMD, chip, 0805, 510Ω, ±5%, 0.125W | TME România | 0.01723 | 0.5169
17 | 680 | (LINK) (https://www.tme.eu/ro/details/smd0805-680r/rezistente-smd-0805/royal-ohm/0805s8j0681t5e/) | SMD0805-680R-5% | 0805S8J0681T5E | ROYAL OHM | rezistor | 30 |  | 1 | Rezistor SMD, chip, 0805, 680Ω, ±5%, 0.125W | TME România | 0.01723 | 0.5169
18 | 820 | (LINK) (https://www.tme.eu/ro/details/smd0805-820r/rezistente-smd-0805/royal-ohm/0805s8j0821t5e/) | SMD0805-820R-5% | 0805S8J0821T5E | ROYAL OHM | rezistor | 30 |  |  | Rezistor SMD, chip, 0805, 820Ω, ±5%, 0.125W | TME România | 0.01723 | 0.5169
19 | 910 | (LINK) (https://www.tme.eu/ro/details/rc0805jr-07910r/rezistente-smd-0805/yageo/rc0805jr-07910rl/) | SMD0805-910R-5% | RC0805JR-07910RL | YAGEO | rezistor | 40 |  |  | Rezistor SMD, chip, 0805, 910Ω, ±5%, 0.125W | TME România | 0.0261 | 1.044
20 | 1k | (LINK) (https://www.tme.eu/ro/details/smd0805-1k/rezistente-smd-0805/royal-ohm/0805s8j0102t5e/) | SMD0805-1K-5% | 0805S8J0102T5E | ROYAL OHM | rezistor | 100 |  | 2 | Rezistor SMD, chip, 0805, 1kΩ, ±5%, 0.125W | TME România | 0.01723 | 1.723
21 | 1.5k | (LINK) (https://www.tme.eu/ro/details/wf08p-1k5-5%25/rezistente-smd-0805/walsin/wf08p152jtl/) | SMD0805-1K5-5% | WF08P152JTL | WALSIN | rezistor | 40 |  |  | Rezistor SMD, chip, 0805, 1.5kΩ, ±5%, 0.125W | TME România | 0.0172 | 0.688
22 | 1.8k | (LINK) (https://www.tme.eu/ro/details/smd0805-1k8/rezistente-smd-0805/royal-ohm/0805s8j0182t5e/) | SMD0805-1K8-5% | 0805S8J0182T5E | ROYAL OHM | rezistor | 30 |  |  | Rezistor SMD, chip, 0805, 1.8kΩ, ±5%, 0.125W | TME România | 0.01723 | 0.5169
23 | 2k | (LINK) (https://www.tme.eu/ro/details/smd0805-2k/rezistente-smd-0805/royal-ohm/0805s8j0202t5e/) | SMD0805-2K-5% | 0805S8J0202T5E | ROYAL OHM | rezistor | 80 |  | 1 | Rezistor SMD, chip, 0805, 2kΩ, ±5%, 0.125W | TME România | 0.01723 | 1.3784
24 | 2.2k | (LINK) (https://www.tme.eu/ro/details/smd0805-2k2/rezistente-smd-0805/royal-ohm/0805s8j0222t5e/) | SMD0805-2K2-5% | 0805S8J0222T5E | ROYAL OHM | rezistor | 30 |  |  | Rezistor SMD, chip, 0805, 2.2kΩ, ±5%, 0.125W | TME România | 0.01723 | 0.5169
25 | 2.7k | (LINK) (https://www.tme.eu/ro/details/smd0805-2k7/rezistente-smd-0805/royal-ohm/0805s8j0272t5e/) | SMD0805-2K7-5% | 0805S8F2701T5E | ROYAL OHM | rezistor | 30 |  |  | Rezistor SMD, chip, 0805, 2.7kΩ, ±5%, 0.125W | TME România | 0.01723 | 0.5169
26 | 3.3k | (LINK) (https://www.tme.eu/ro/details/smd0805-3k3/rezistente-smd-0805/royal-ohm/0805s8j0332t5e/) | SMD0805-3K3-5% | 0805S8J0332T5E | ROYAL OHM | rezistor | 20 |  |  | Rezistor SMD, chip, 0805, 3.3kΩ, ±5%, 0.125W | TME România | 0.01723 | 0.3446
27 | 3.9k | (LINK) (https://www.tme.eu/ro/details/smd0805-3k9/rezistente-smd-0805/royal-ohm/0805s8j0392t5e/) | SMD0805-3K9-5% | 0805S8J0392T5E | ROYAL OHM | rezistor | 20 |  | 1 | Rezistor SMD, chip, 0805, 3.9kΩ, ±5%, 0.125W | TME România | 0.01723 | 0.3446
28 | 4.7k | (LINK) (https://www.tme.eu/ro/details/smd0805-4k7/rezistente-smd-0805/royal-ohm/0805s8j0472t5e/) | SMD0805-4K7-5% | 0805S8J0472T5E | ROYAL OHM | rezistor | 30 |  |  | Rezistor SMD, chip, 0805, 4.7kΩ, ±5%, 0.125W | TME România | 0.01723 | 0.5169
29 | 5.6k | (LINK) (https://www.tme.eu/ro/details/smd0805-5k6/rezistente-smd-0805/royal-ohm/0805s8j0562t5e/) | SMD0805-5K6-5% | 0805S8J0562T5E | ROYAL OHM | rezistor | 40 |  | 1 | Rezistor SMD, chip, 0805, 5.6kΩ, ±5%, 0.125W | TME România | 0.01723 | 0.6892
30 | 6.8k | (LINK) (https://www.tme.eu/ro/details/rc0805jr-076k8/rezistente-smd-0805/yageo/rc0805jr-076k8l/) | SMD0805-6K8-5% | RC0805JR-076K8L | YAGEO | rezistor | 20 |  |  | Rezistor SMD, chip, 0805, 6.8kΩ, ±5%, 0.125W | TME România | 0.0261 | 0.522
31 | 8.2k | (LINK) (https://www.tme.eu/ro/details/smd0805-8k2/rezistente-smd-0805/royal-ohm/0805s8j0822t5e/) | SMD0805-8K2-5% | 0805S8J0822T5E | ROYAL OHM | rezistor | 30 |  | 1 | Rezistor SMD, chip, 0805, 8.2kΩ, ±5%, 0.125W | TME România | 0.01723 | 0.5169
32 | 9.1k | (LINK) (https://www.tme.eu/ro/details/smd0805-9k1/rezistente-smd-0805/royal-ohm/0805s8j0912t5e/) | SMD0805-9K1-5% | 0805S8J0912T5E | ROYAL OHM | rezistor | 20 |  |  | Rezistor SMD, chip, 0805, 9.1kΩ, ±5%, 0.125W | TME România | 0.01723 | 0.3446
33 | 10k | (LINK) (https://www.tme.eu/ro/details/smd0805-10k/rezistente-smd-0805/royal-ohm/0805s8j0103t5e/) | SMD0805-10K-5% | 0805S8J0103T5E | ROYAL OHM | rezistor | 100 |  | 1 | Rezistor SMD, chip, 0805, 10kΩ, ±5%, 0.125W | TME România | 0.01723 | 1.723
34 | 15k | (LINK) (https://www.tme.eu/ro/details/smd0805-15k/rezistente-smd-0805/royal-ohm/0805s8j0153t5e/) | SMD0805-15K-5% | 0805S8J0153T5E | ROYAL OHM | rezistor | 30 |  |  | Rezistor SMD, chip, 0805, 15kΩ, ±5%, 0.125W | TME România | 0.01723 | 0.5169
35 | 22k | (LINK) (https://www.tme.eu/ro/details/smd0805-22k/rezistente-smd-0805/royal-ohm/0805s8j0223t5e/) | SMD0805-22K-5% | 0805S8J0223T5E | ROYAL OHM | rezistor | 30 |  |  | Rezistor SMD, chip, 0805, 22kΩ, ±5%, 0.125W | TME România | 0.01723 | 0.5169
36 | 47k | (LINK) (http://www.tme.eu/ro/details/smd0805-47k/rezistente-smd-0805/royal-ohm/0805s8j0473t5e/) | SMD0805-47K-5% | 0805S8J0473T5E | ROYAL OHM | rezistor | 40 |  |  | Rezistor: thick film; SMD; 0805; 47kΩ; 0,125W; ±5%; -55÷125°C | TME România | 0.01723 | 0.6892
37 | 68k | (LINK) (https://www.tme.eu/ro/details/smd0805-68k/rezistente-smd-0805/royal-ohm/0805s8j0683t5e/) | SMD0805-68K-5% | 0805S8J0683T5E | ROYAL OHM | rezistor | 20 |  |  | Rezistor SMD, chip, 0805, 68kΩ, ±5%, 0.125W | TME România | 0.01723 | 0.3446
38 | 100k | (LINK) (https://www.tme.eu/ro/details/smd0805-100k/rezistente-smd-0805/royal-ohm/0805s8j0104t5e/) | SMD0805-100K-5% | 0805S8J0104T5E | ROYAL OHM | rezistor | 100 |  |  | Rezistor SMD, chip, 0805, 100kΩ, ±5%, 0.125W | TME România | 0.01723 | 1.723
39 | 150k | (LINK) (http://www.tme.eu/ro/details/smd0805-150k/rezistente-smd-0805/royal-ohm/0805s8j0154t5e/) | SMD0805-150K-5% | 0805S8J0154T5E | ROYAL OHM | rezistor | 30 |  |  | Rezistor SMD, chip, 0805, 150kΩ, ±5%, 0.125W | TME România | 0.01723 | 0.5169
40 | 180k | (LINK) (http://www.tme.eu/ro/details/smd0805-180k/rezistente-smd-0805/royal-ohm/0805s8j0184t5e/) | SMD0805-180K-5% | 0805S8J0184T5E | ROYAL OHM | rezistor | 30 |  |  | Rezistor SMD, chip, 0805, 180kΩ, ±5%, 0.125W | TME România | 0.01723 | 0.5169
41 | 220k | (LINK) (https://www.tme.eu/ro/details/smd0805-220k/rezistente-smd-0805/royal-ohm/0805s8j0224t5e/) | SMD0805-220K-5% | 0805S8J0224T5E | ROYAL OHM | rezistor | 30 |  |  | Rezistor SMD, chip, 0805, 220kΩ, ±5%, 0.125W | TME România | 0.01723 | 0.5169
42 | 330k | (LINK) (https://www.tme.eu/ro/details/smd0805-330k/rezistente-smd-0805/royal-ohm/0805s8j0334t5e/) | SMD0805-330K-5% | 0805S8J0334T5E | ROYAL OHM | rezistor | 30 |  |  | Rezistor SMD, chip, 0805, 330kΩ, ±5%, 0.125W | TME România | 0.01723 | 0.5169
43 | 390k | (LINK) (https://www.tme.eu/ro/details/smd0805-390k/rezistente-smd-0805/royal-ohm/0805s8j0394t5e/) | SMD0805-390K-5% | 0805S8J0394T5E | ROYAL OHM | rezistor | 30 |  |  | Rezistor SMD, chip, 0805, 390kΩ, ±5%, 0.125W | TME România | 0.01723 | 0.5169
44 | 510k | (LINK) (https://www.tme.eu/ro/details/smd0805-510k/rezistente-smd-0805/royal-ohm/0805s8j0514t5e/) | SMD0805-510K-5% | 0805S8J0514T5E | ROYAL OHM | rezistor | 30 |  |  | Rezistor SMD, chip, 0805, 510kΩ, ±5%, 0.125W | TME România | 0.01723 | 0.5169
45 | 1M | (LINK) (https://www.tme.eu/ro/details/crcw08051m00jntabc/rezistente-smd-0805/vishay/) | SMD0805-1M-5% | CRCW08051M00JNTABC | VISHAY | rezistor | 0 |  |  | Rezistor SMD, chip, 0805, 1MΩ, ±5%, 0.125W | TME România | 0.01151 | 0
46 | 2M | (LINK) (http://www.tme.eu/ro/details/smd0805-2m/rezistente-smd-0805/royal-ohm/0805waj-2m-t5e/) | SMD0805-2M7 5% | 0805WAJ 2M T5E | ROYAL OHM | rezistor | 0 |  |  | Rezistor SMD, chip, 0805, 2MΩ, ±1%, 0.125W | TME România | 0.01723 | 0
47 | 5,1M | (LINK) (http://www.tme.eu/ro/details/smd0805-5m1/rezistente-smd-0805/royal-ohm/0805s8j0515t5e/) | SMD0805-5M1 5% | RC0805FR-075M1 | Yageo | rezistor | 0 |  |  | Rezistor SMD, chip, 0805, 5.1MΩ, ±1%, 0.125W | TME România | 0.01723 | 0
48 | 10M | (LINK) (https://www.tme.eu/ro/details/0805s8j0106t5e/rezistente-smd-0805/royal-ohm/) | SMD0805-10M 5% | 0805S8J0106T5E | ROYAL OHM | rezistor | 0 |  |  | Rezistor SMD, chip, 0805, 10MΩ, ±5%, 0.125W | TME România | 0.01723 | 0
49 | 100ohm | (LINK) (https://www.tme.eu/ro/details/ts53yl100r/trimere-smd-cu-o-singura-tura/vishay/ts53yl101mr10/) | 1804GSMD-100R | 1804GSMD-100R | SR PASSIVES | potențiometru | 15 |  |  | Potențiome-tru liniar, simplă tură, SMD, 100Ω, ±10%, 100ppm/°C, 0.25W | TME România | 3.77 | 56.55
50 | 500ohm | (LINK) (https://www.tme.eu/ro/details/ts53yl500r/trimere-smd-cu-o-singura-tura/vishay/ts53yl501mr10/) | 1804GSMD-500R | 1804GSMD-500R | VISHAY | potențiometru | 0 |  |  | Potențiome-tru liniar, simplă tură, SMD, 500Ω, ±10%, 100ppm/°C, 0.25W | TME România | 2.19 | 0
51 | 2k | (LINK) (https://www.tme.eu/ro/details/ts53yl2k/trimere-smd-cu-o-singura-tura/vishay/ts53yl202mr10/) | TS53YL202MR10 | TS53YL202MR10 | VISHAY | potențiometru | 0 |  |  | Potențiome-tru liniar, simplă tură, SMD, 2kΩ, ±20%, 100ppm/°C, 0.25W | TME România | 2.84 | 0
52 | 5k | (LINK) (http://www.tme.eu/ro/details/3314g-1-502e/trimere-smd-cu-o-singura-tura/bourns/) | 3314G-1-502E | 3314G-1-502E | BOURNS | potențiometru | 40 |  |  | Potențiome-tru liniar, simplă tură, SMD, 5kΩ, ±20%, 100ppm/°C, 0.25W | TME România | 3.45 | 138
53 | 10k | (LINK) (http://www.tme.eu/ro/details/3314g-1-103e/trimere-smd-cu-o-singura-tura/bourns/) | 3314G-1-103E | 3314G-1-103E | BOURNS | potențiometru | 20 |  | 1 | Potențiome-tru liniar, simplă tură, SMD, 10kΩ, ±20%, 100ppm/°C, 0.25W | TME România | 3.0573 | 61.146
54 | 50k | (LINK) (http://www.tme.eu/ro/details/3314g-1-503e/trimere-smd-cu-o-singura-tura/bourns/) | 3314G-1-503E | 3314G-1-503E | BOURNS | potențiometru | 0 |  |  | Potențiome-tru liniar, simplă tură, SMD, 50kΩ, ±20%, 100ppm/°C, 0.25W | TME România | 2.84 | 0
55 | 100k | (LINK) (http://www.tme.eu/ro/details/ts53yl100k/trimere-smd-cu-o-singura-tura/vishay/ts53yl104mr10/) | TS53YL104MR10 | TS53YL104MR10 | VISHAY | potențiometru | 10 |  |  | Potențiome-tru liniar, simplă tură, SMD, 100kΩ, ±20%, 100ppm/°C, 0.25W | TME România | 2.61 | 26.1
56 | 500k | (LINK) (http://www.tme.eu/ro/details/3314g-1-504e/trimere-smd-cu-o-singura-tura/bourns/) | 3314G-1-504E | 3314G-1-504E | BOURNS | potențiometru | 0 |  |  | Potențiome-tru liniar, simplă tură, SMD, 500kΩ, ±10%, 100ppm/°C, 0.25W | TME România | 2.8802 | 0
 | TOTAL - Componente pasive (rezistoare de valori fixe şi reglabile) |  |  |  |  |  |  |  |  | FARA TVA = | 308.4514 | CU TVA= | 382.479736
57 | 4.7pF | (LINK) (http://www.tme.eu/ro/details/cc0805crnpo94r7/condensatoare-mlcc-smd-0805/yageo/cc0805crnpo9bn4r7/) | CC0805CRNPO9BN4R7 | CC0805CRNPO9BN4R7 | YAGEO | condensator | 20 |  |  | ceramic; MLCC; 4,7pF; 50V; C0G; ±0,25pF; SMD; 0805 | TME România | 0.16643 | 3.3286
58 | 10pF | (LINK) (http://www.tme.eu/ro/details/cc0805jrnpo9100/condensatoare-mlcc-smd-0805/yageo/cc0805jrnpo9bn100/) | CC0805JRNPO9BN100 | CC0805JRNPO9BN100 | YAGEO | condensator | 20 |  |  | ceramic; MLCC; 10pF; 50V; C0G; ±5%; SMD; 0805 | TME România | 0.1649 | 3.298
59 | 47pF | (LINK) (http://www.tme.eu/ro/details/cl21c470jbannnc/condensatoare-mlcc-smd-0805/samsung/) | CL21C470JBANNNC | CL21C470JBANNNC | SAMSUNG | condensator | 20 |  |  | Condensator: ceramic; MLCC; 47pF; 50V; C0G; ±5%; SMD; 0805; -55÷125°C | TME România | 0.11097 | 2.2194
60 | 100pF | (LINK) (http://www.tme.eu/ro/details/cl21c101jbannnc/condensatoare-mlcc-smd-0805/samsung/) | CL21C101JBANNNC | CL21C101JBANNNC | SAMSUNG | condensator | 20 |  |  | Condensator: ceramic; MLCC; 100pF; 50V; C0G; ±5%; SMD; 0805 | TME România | 0.05427 | 1.0854
61 | 470pF | (LINK) (https://www.tme.eu/ro/details/cl21c471jbannnc/condensatoare-mlcc-smd-0805/samsung/) | CL21C471JBANNNC | CL21C471JBANNNC | SAMSUNG | condensator | 20 |  |  | Condensator: ceramic; MLCC; 470pF; 50V; X7R; ±10%; SMD; 0805 | TME România | 0.12123 | 2.4246
62 | 1nF | (LINK) (https://www.tme.eu/ro/details/cl21c102jbcnnnc/condensatoare-mlcc-smd-0805/samsung/) | CL21C102JBCNNNC | CL21C102JBCNNNC | SAMSUNG | condensator | 0 |  |  | Condensator MLCC, SMD, 0805, 1nF, ±5%, 50V, C0G | TME România | 0.06487 | 0
63 | 2.2nF | (LINK) (https://www.tme.eu/ro/details/cl21b222jbannnc/condensatoare-mlcc-smd-0805/samsung/) | CL21B222JBANNNC | CL21B222JBANNNC | SAMSUNG | condensator | 0 |  |  | Condensator: ceramic; MLCC; 2,2nF; 50V; X7R; ±10%; SMD; 0805 | TME România | 0.1485 | 0
64 | 4.7nF | (LINK) (https://www.tme.eu/ro/details/cl21b472kbannnc/condensatoare-mlcc-smd-0805/samsung/) | CL21B472KBANNNC | CL21B472KBANNNC | SAMSUNG | condensator | 0 |  |  | Condensator MLCC, SMD, 0805, 4.7nF, ±5%, 50V, X7R | TME România | 0.08943 | 0
65 | 5.6nF | (LINK) (https://www.tme.eu/ro/details/cl21b562kbannnc/condensatoare-mlcc-smd-0805/samsung/) | CL21B562KBANNNC | CL21B562KBANNNC | SAMSUNG | condensator | 0 |  |  | Condensator MLCC, SMD, 0805, 5.6nF, ±5%, 50V, X7R | TME România | 0.04517 | 0
66 | 10nF | (LINK) (https://www.tme.eu/ro/details/cl21b103kbannnd/condensatoare-mlcc-smd-0805/samsung/) | CL21B103KBANNND | CL21B103KBANNND | SAMSUNG | condensator | 40 |  |  | Condensator MLCC, SMD, 0805, 10nF, ±5%, 50V, X7R | TME România | 0.06093 | 2.4372
67 | 22nF | (LINK) (http://www.tme.eu/ro/details/cl21b223kcfnnne/condensatoare-mlcc-smd-0805/samsung/) | CL21B223KBANNNC | CL21B223KBANNNC | SAMSUNG | condensator | 0 |  |  | Condensator: ceramic; MLCC; 22nF; 100V; X7R; ±10%; SMD; 0805 | TME România | 0.13823 | 0
68 | 33nF | (LINK) (https://www.tme.eu/ro/details/vj0805y333kxacw1bc/condensatoare-mlcc-smd-0805/vishay/) | VJ0805Y333KXACW1BC | VJ0805Y333KXACW1BC | VISHAY | condensator | 0 |  |  | Condensator: ceramic; MLCC; 33nF; 50V; X7R; ±10%; SMD; 0805 | TME România | 0.05417 | 0
69 | 100nF | (LINK) (https://www.tme.eu/ro/details/cl21f104zbcnnnc/condensatoare-mlcc-smd-0805/samsung/) | CL21F104ZBCNNNC | CL21F104ZBCNNNC | SAMSUNG | condensator | 40 |  |  | ceramic; MLCC; 100nF; 50V; X7R; ±10%; SMD; 0805 | TME România | 0.3759 | 15.036
70 | 220nF | (LINK) (http://www.tme.eu/ro/details/cl21b224kafnnne/condensatoare-mlcc-smd-0805/samsung/) | CL21B224KAFNNNE | CL21B224KAFNNNE | SAMSUNG | condensator | 0 |  |  | Condensator: ceramic; MLCC; 220nF; 25V; X7R; ±10%; SMD; 0805 | TME România | 0.10247 | 0
71 | 330nF | (LINK) (https://www.tme.eu/ro/details/grm219r71h334ka88d/condensatoare-mlcc-smd-0805/murata/) | GRM219R71H334KA88D | GRM219R71H334KA88D | MURATA | condensator | 0 |  |  | Condensator: ceramic; MLCC; 330nF; 50V; X7R; ±10%; SMD; 0805 | TME România | 0.5972 | 0
72 | 470nF | (LINK) (https://www.tme.eu/ro/details/cc0805mry5v8474/condensatoare-mlcc-smd-0805/yageo/cc0805mry5v8bb474/) | CC0805MRY5V8474 | CC0805MRY5V8BB474 | YAGEO | condensator | 0 |  |  | Condensator: ceramic; MLCC; 470nF; 50V; Y5V; -20÷+80%; SMD; 0805 | TME România | 0.0758 | 0
73 | 1uF | (LINK) (https://www.tme.eu/ro/details/cl21b105kbfnnng/condensatoare-mlcc-smd-0805/samsung/) | CL21B105KBFNNNG | CL21B105KBFNNNG | SAMSUNG | condensator | 20 |  |  | Condensator: ceramic; MLCC; 1uF; 50V; X7R; ±20%; SMD; 0805 | TME România | 0.25253 | 5.0506
74 | 2.2uF | (LINK) (https://www.tme.eu/ro/details/grm21br61h225ka73l/condensatoare-mlcc-smd-0805/murata/) | GRM21BR61H225KA73L | GRM21BR61H225KA73L | MURATA | condensator | 20 |  |  | Condensator: ceramic; MLCC; 2,2uF; 25V; X5R; ±10%; SMD; 0805 | TME România | 0.4486 | 8.972
75 | 4.7uF | (LINK) (https://www.tme.eu/ro/details/cl21a475kaqnnng/condensatoare-mlcc-smd-0805/samsung/) | CL21A475KAQNNNG | CL21A475KAQNNNG | SAMSUNG | condensator | 20 |  |  | ceramic; MLCC; 4,7uF; 25V; X5R; ±10%; SMD; 0805 | TME România | 0.25373 | 5.0746
76 | 10uF | (LINK) (https://www.tme.eu/ro/details/ce10_50-smd/condensatoare-electrolitice-smd-85c/) | CE10/50-SMD | CE10/50-SMD | TME | condensator | 16 |  |  | Condensator: electrolitic; SMD; 10uF; 50V | TME România | 0.2284 | 3.6544
 | TOTAL - Componente pasive (condensatoare) |  |  |  |  |  |  |  |  | FARA TVA = | 52.5808 | CU TVA= | 65.200192
77 | 4148 | (LINK) (http://www.tme.eu/ro/details/1n4148-0805/diode-universale-smd/dc-components/cd4148ws0805c/) | 1N4148-0805 | CD4148WS(0805C) | DC Components | diodă pn | 40 |  |  | Diodă comutație, SMD, 0805, 300mA, 100V | TME România | 0.04555 | 1.822
78 | LED | (LINK) (https://www.tme.eu/ro/details/of-smd2012b/diode-led-smd-colorate/optoflash/) | OF-SMD2012B | OF-SMD2012B | OPTOFLASH | LED | 15 |  | 2 | LED albastru, SMD, 0805, 150-200mcd, 476nm, 120° | TME România | 0.1264 | 1.896
79 | 2.7V | (LINK) (https://www.tme.eu/ro/details/bzx84-c2v7.215/diode-zener-smd/nexperia/bzx84-c2v7-215/) | BZX84C2V7 | BZX84-C2V7LT1G | ON Semiconductor | diodă Zener | 5 |  |  | Diodă Zener, SMD, SOT23, 2,7V, ±5%, 0.25W | TME România | 0.05732 | 0.2866
80 | 5.1V | (LINK) (https://www.tme.eu/ro/details/bzx84-c5v1.215/diode-zener-smd/nexperia/) | BZX84C5V1 | BZX84-C5V1 | NEXPERIA | diodă Zener | 10 |  | 1 | Diodă Zener, SMD, SOT23, 5,1V, ±5%, 0.3W | TME România | 0.06245 | 0.6245
81 | 5.6V | (LINK) (https://www.tme.eu/ro/details/bzx84b5v6-dio/diode-zener-smd/diotec-semiconductor/bzx84b5v6/) | BZX84B5V6 | BZX84B5V6 | DIOTEC SEMICONDUCTOR | diodă Zener | 10 |  |  | Diodă Zener, SMD, SOT23, 5,6V, ±5%, 0.3W | TME România | 0.0839 | 0.839
82 | 6.2V | (LINK) (https://www.tme.eu/ro/details/bzx84-c6v2.215/diode-zener-smd/nexperia/) | BZX84C6V2 | BZX84-C6V2 | NEXPERIA | diodă Zener | 5 |  |  | Diodă Zener, SMD, SOT23, 6.2V, ±5%, 0.3W | TME România | 0.06618 | 0.3309
83 | 6.8V | (LINK) (https://www.tme.eu/ro/details/bzx84-c6v8.215/diode-zener-smd/nexperia/) | BZX84C6V8 | BZX84-C6V8 | NEXPERIA | diodă Zener | 0 |  |  | Diodă Zener, SMD, SOT23, 6.8V, ±5%, 0.3W | TME România | 0.05686 | 0
84 | 8.2V | (LINK) (https://www.tme.eu/ro/details/bzx84-c8v2.215/diode-zener-smd/nexperia/) | BZX84C8V2 | BZX84-C8V2 | NEXPERIA | diodă Zener | 5 |  |  | Diodă Zener, SMD, SOT23, 8.2V, ±5%, 0.3W | TME România | 0.05686 | 0.2843
85 | 10V | (LINK) (https://www.tme.eu/ro/details/bzx84-c10.215/diode-zener-smd/nexperia/) | BZX84C10 | BZX84-C10 | NEXPERIA | diodă Zener | 5 |  |  | Diodă Zener, SMD, SOT23, 10V, ±5%, 0.3W | TME România | 0.05686 | 0.2843
86 | PNP | (LINK) (http://www.tme.eu/ro/details/bc856b-dio/tranzistori-smd-pnp/diotec-semiconductor/bc856b/) | BC856B | BC856B | DIOTEC | tranzistor bipolar | 80 |  | 2 | Tranzistor bipolar PNP, SMD, SOT23, 80V, 100mA | TME România | 0.04055 | 3.244
87 | NPN | (LINK) (https://www.tme.eu/ro/details/bc846b-dio/tranzistori-smd-npn/diotec-semiconductor/bc846b/) | BC846B | BC846B | DIOTEC | tranzistor bipolar | 80 |  | 6 | Tranzistor bipolar NPN, SMD, SOT23, 65V, 100mA | TME România | 0.03379 | 2.7032
89 | N-JFET | (LINK) (http://www.tme.eu/ro/details/mmbfj309lt1g/tranzistori-canal-n-smd/on-semiconductor/) | MMBFJ309LT1G | MMBFJ309LT1G | ON Semiconductor | tranzistor NJFET | 40 |  |  | Tranzistor N-JFET, SMD, SOT23, 25V, 30mA | TME România | 0.8063 | 32.252
90 | P-JFET | (LINK) (http://www.tme.eu/ro/details/mmbfj177lt1g/tranzistori-canal-p-smd/on-semiconductor/) | MMBFJ177LT1G | MMBFJ177LT1G | ON Semiconductor | tranzistor PJFET | 15 |  |  | Tranzistor P-JFET, SMD, SOT23, 30V, 20mA | TME România | 0.8808 | 13.212
91 | NPN | (LINK) (http://www.tme.eu/ro/details/bc817-25-dio/tranzistori-smd-npn/diotec-semiconductor/bc817-25/) | BC817-25-DIO | BC817-25-DIO | NXP | tranzistor bipolar | 10 |  |  | Tranzistor bipolar NPN, SMD, SOT23, 45V, 800mA | TME România | 0.0494 | 0.494
93 | PNP | (LINK) (http://www.tme.eu/ro/details/bc807-25-dio/tranzistori-smd-pnp/diotec-semiconductor/bc807-25/) | BC807-25-DIO | BC807-25-DIO | NXP | tranzistor bipolar | 10 |  |  | Tranzistor bipolar PNP, SMD, SOT23, 45V, 800mA | TME România | 0.05406 | 0.5406
94 | NPN | (LINK) (http://www.tme.eu/ro/details/mjd31cg/tranzistori-smd-npn/on-semiconductor/) | MJD31CG | MJD31CG | ON Semiconductor | tranzistor bipolar | 15 |  | 1 | Tranzistor bipolar NPN, SMD, DPACK, 100V, 3A, 15W | TME România | 0.7037 | 10.5555
96 | PNP | (LINK) (http://www.tme.eu/ro/details/mjd32cg/tranzistori-smd-pnp/on-semiconductor/) | MJD32CG | MJD32CG | ON Semiconductor | tranzistor bipolar | 15 |  |  | Tranzistor bipolar PNP, SMD, DPACK, 100V, 3A, 15W | TME România | 0.783 | 11.745
97 | Nmos | (LINK) (http://www.tme.eu/ro/details/irfr120npbf/tranzistori-canal-n-smd/international-rectifier/) | IRFR120NPBF | IRFR120NPBF | International Rectifier | tranzistor NMOS | 10 |  |  | Tranzistor N-MOSFET, SMD, DPAK, 100V, 9.1A, 20V, 39W | TME România | 1.03 | 10.3
 | TOTAL - Componente semiconductoare (tranzistoare bipolare şi cu efect de câmp, diode, LED, etc.) |  |  |  |  |  |  |  |  | FARA TVA = | 118.7139 | CU TVA= | 147.205236
98 | Conn2p | (LINK) (http://www.tme.eu/ro/details/zl301-40p/pini-cu-benzi-si-soclu/ninigi/) | ZL301-40P | ZL301-40P | NINIGI | Sir pini, pas 2,54mm, SMD | 6 |  |  | Sir pini, pas 2,54mm, SMD, tip tata, bareta de 40 pini | TME România | 2.3027 | 13.8162
99 | FUSE | (LINK) (http://www.tme.eu/ro/details/3413.0116.11/sigurante-smd-1206-ultrarapide/schurter/) | 3413.0116.11 | 3413.0116.11 | SCHURTER | sigu-ranță | 0 |  |  | Siguranță sticlă, SMD, 1206, 1.25A, 48mΩ | TME România | 0 | 0
 | Total - Conectică, sigurante fuzibile, etc. |  |  |  |  |  |  |  |  | FARA TVA = | 13.8162 | CU TVA= | 17.132088
 | Total general |  |  |  |  |  |  |  |  | FARA TVA = | 493.5623 | CU TVA= | 587.339137

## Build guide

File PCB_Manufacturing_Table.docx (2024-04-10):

General info document for PCB manufacturing
No. | Item Name | File Name | | | | | | Info / Remarks / Notes
| BOARD
1 | Board Name / Number | PCB_STABILIZATOR_EFTIMIE1.brd | | | | | | -
2 | Revision Date | 10 December 2023 | | | | | | -
3 | Board Size | 40 x 40 mm² | | | | | | -
4 | Board Quantity | 1 | | | | | | -
5 | Material / Dielectric Type | FR4 | | | | | | -
6 | Board Thickness | 1.6 mm | | | | | | -
7 | Copper Thickness | 35 μm | | | | | | -
| LAYERS
8 | Number of Electrical Layers | 2 | | | | | | -
9 | Copper Layer TOP | TOP.art | | | | | | -
10 | Copper Layer BOTTOM | BOTTOM.art | | | | | | -
11 | Copper GND Plane | - | | | | | | -
12 | Copper PWR Plane | - | | | | | | -
13 | Copper INNER 1 | - | | | | | | -
14 | Copper INNER 2 | - | | | | | | -
15 | Solder Mask TOP | SMTOP.art | | | | | | -
16 | Solder Mask BOTTOM | SMBOT.art | | | | | | -
17 | Solder Paste TOP | SPTOP.art | | | | | | -
18 | Solder Paste BOTTOM | - | | | | | | -
19 | Peelable Mask TOP | - | | | | | | -
20 | Peelable Mask BOTTOM | - | | | | | | -
21 | Silk Screen TOP | SSTOP.art | | | | | | -
22 | Silk Screen BOTTOM | - | | | | | | -
23 | Board Outline | BO.art | | | | | | -
24 | Fabrication Drawing | FAB.art | | | | | | -
| MILLING & DRILLING
25 | Mill Drawing | - | | | | | | -
26 | Drill Drawing | - | | | | | | -
27 | N.C. Drill (for both PH & NPH) | DRILL.drl | | | | | | -
28 | N.C. Drill / Plated Holes (PH) | - | | | | | | -
29 | N.C. Drill / Non-Plated Holes (PH) | - | | | | | | -
| FINISHING
30 | Panelisation | - | | | | | | -
31 | Electrical Test | - | | | | | | -
32 | Copper Finishing | x | HASL | | OSP | | | ENIG
33 | Board Outline Machining | | Routing | | Milling | | x | V-Cutting
34 | Final remarks | - | | | | -

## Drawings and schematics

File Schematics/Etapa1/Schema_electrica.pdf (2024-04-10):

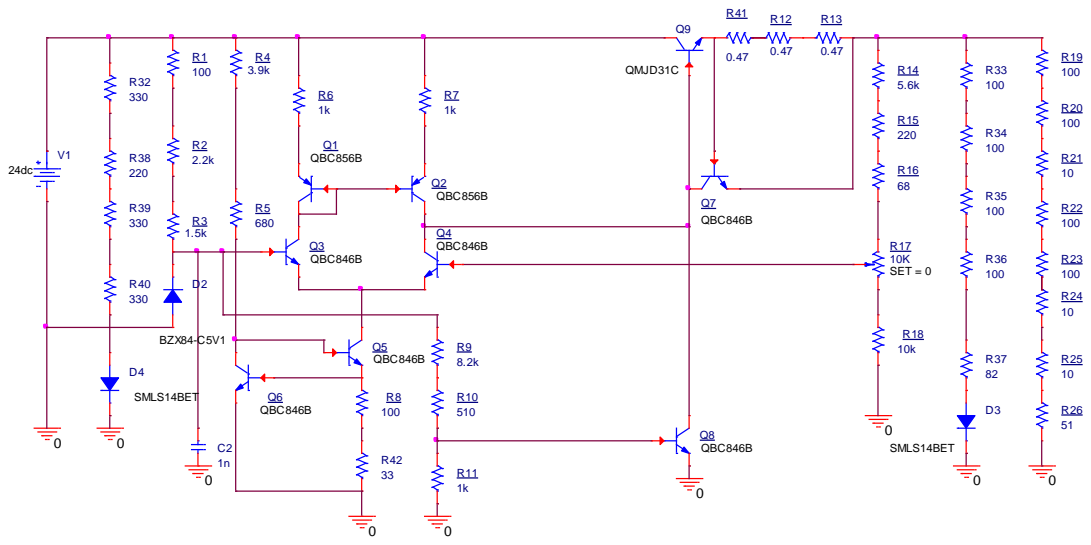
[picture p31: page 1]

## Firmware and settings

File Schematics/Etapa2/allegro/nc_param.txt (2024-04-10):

INTEGER-PLACES         2
DECIMAL-PLACES         5
X-OFFSET               0.000000
Y-OFFSET               0.000000
FEEDRATE               1
COORDINATES            ABSOLUTE
OUTPUT-UNITS           ENGLISH
TOOL-ORDER             INCREASING
REPEAT-CODES           YES
SUPPRESS-LEAD-ZEROES   YES
SUPPRESS-TRAIL-ZEROES  NO
SUPPRESS-EQUAL         NO
TOOL-SELECT            YES
OPTIMIZE_DRILLING      NO
ENHANCED_EXCELLON      YES
TAPE-FILE              D:/proiectul_meu/allegro/DRILL.drl
HEADER                 none
LEADER                 12
CODE                   ASCII
SEPARATE               NO
SEPARATE-ROUTING       NO
DRILLING               LAYER-PAIR
BACKDRILL              NO
CAVITY                 NO

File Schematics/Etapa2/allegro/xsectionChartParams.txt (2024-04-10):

LAYER_NAME YES
LAYER_THICKNESS YES
MATERIAL_NAME YES
EMB_STATUS NO
ATTACH_METHOD NO
LAYER_TYPE YES
DRILL_SPAN YES
STACKED_VIAS YES
EMD_COMP_LEGEND  NO
DRILL_LABEL  YES
X_SCALE_FACTOR  1.000
DIELECTRIC_SCALE_FACTOR  1.000
TEXT_BLOCK  1
MAX_CHART_HEIGHT 2000 MIL
